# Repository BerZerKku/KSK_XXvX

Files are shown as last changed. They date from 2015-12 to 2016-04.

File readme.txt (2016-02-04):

Плата KSK

02v5

При вводе СП в 1С учесть что часть элементов отсутствует в БД.
На сборочнике надо перевернуть один стабилитрон, спросить у Феди.

Код ПП: 3.140.016
Код ПП в сборе: 2.140.243

Стэк:
35мкм  TOP 
1.5мм e=4.5
35мкм  BOTTOM

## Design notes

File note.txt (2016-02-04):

Диоды VD101,102 заменить на SMBJ48A.
Диоды VD1,VD13 заменить на TZMC5V1-GS08.
Чип-резисторы R3,R25.. заменить на 0603-21K-1%.

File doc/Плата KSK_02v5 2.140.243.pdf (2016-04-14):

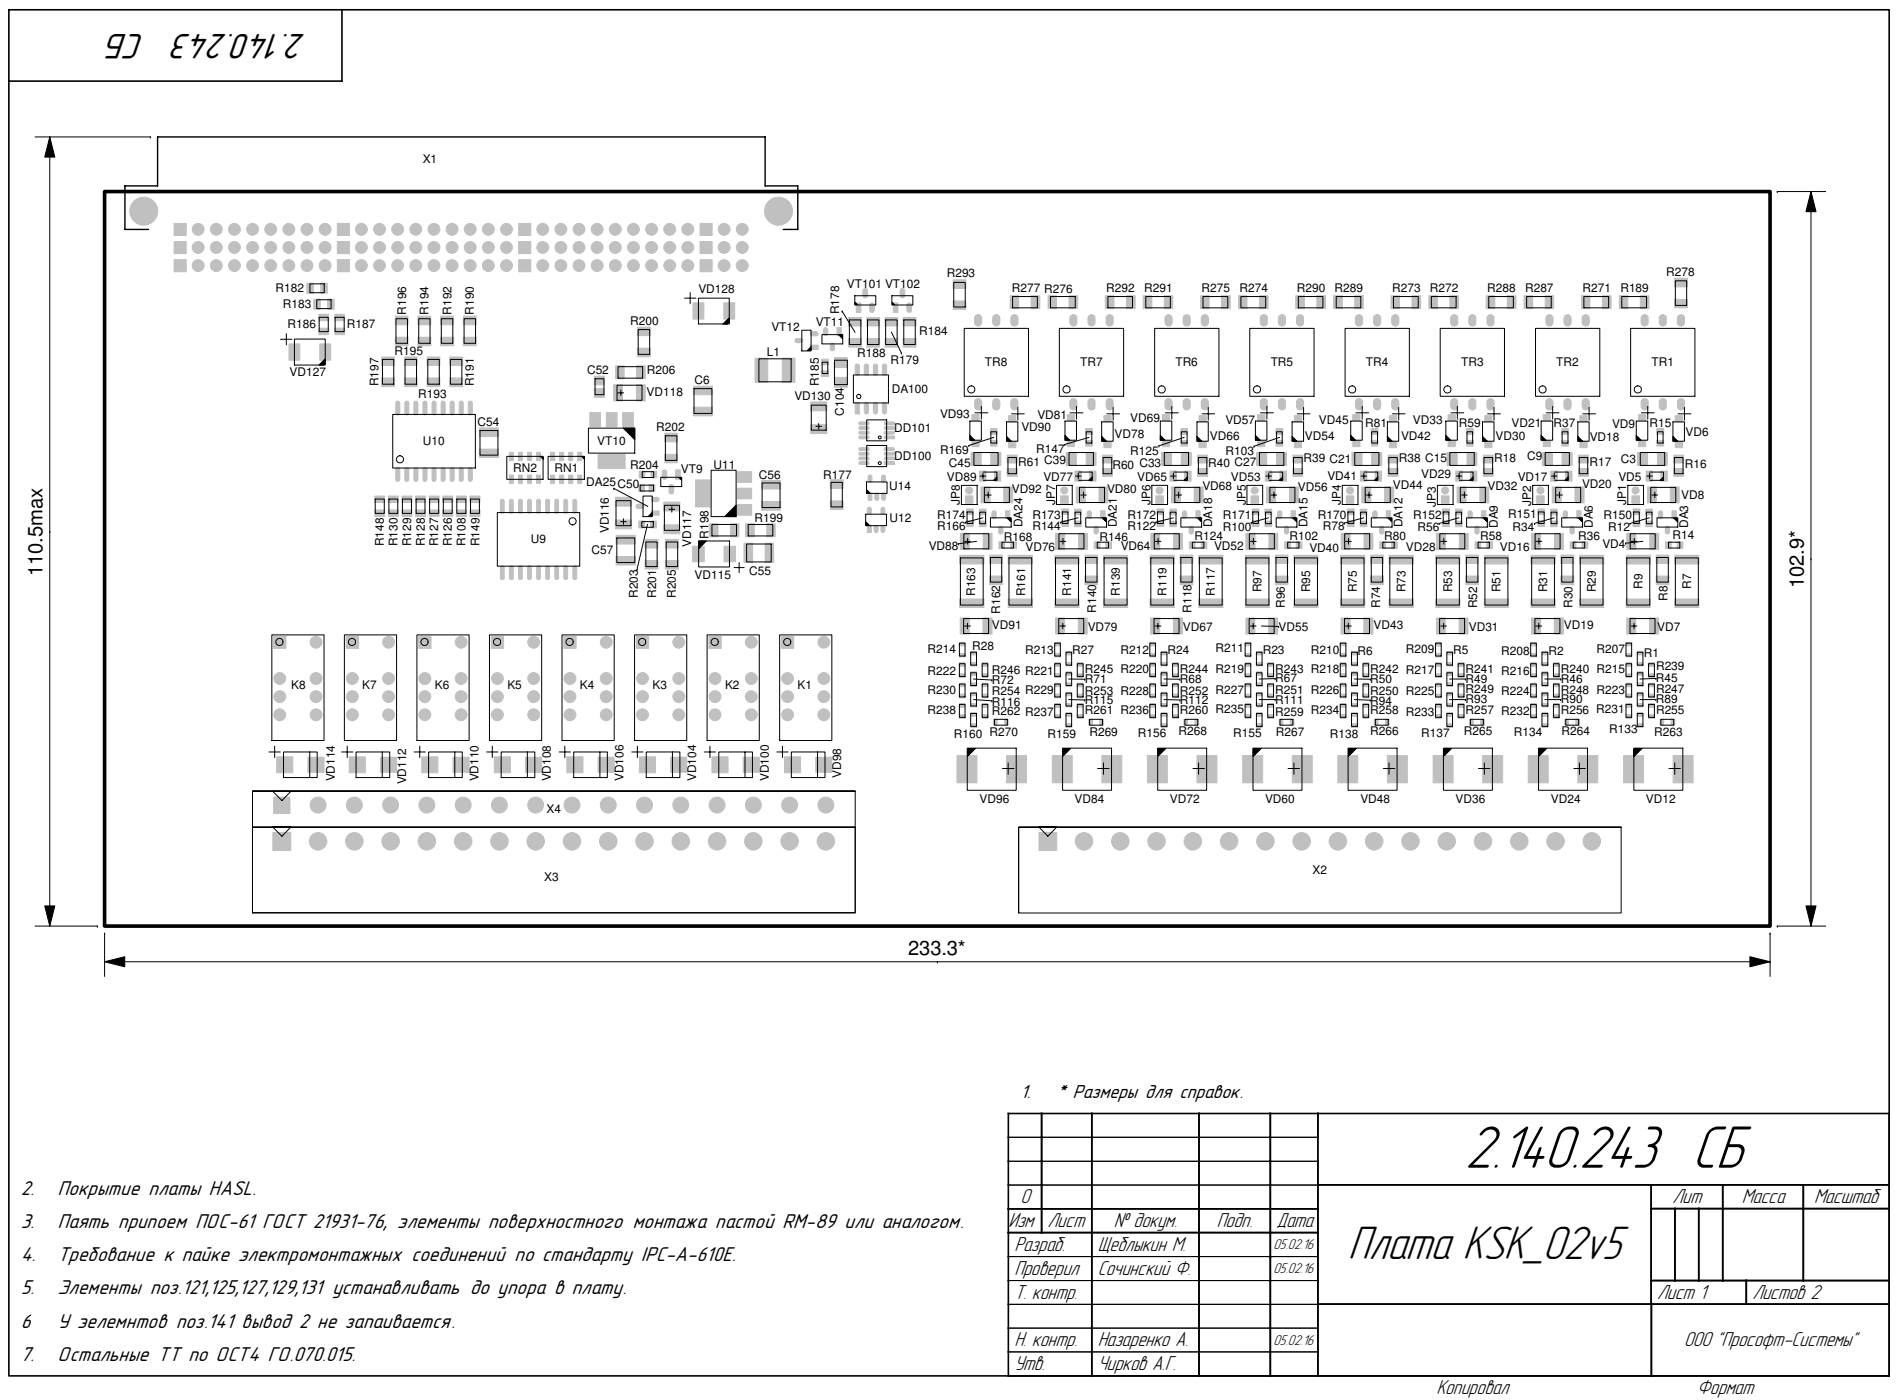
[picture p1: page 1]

2. Покрытие платы HASL.
3. Паять припоем ПОС-61 ГОСТ 21931-76, элементы поверхностного монтажа пастой RM-89 или аналогом.
4. Требование к пайке электромонтажных соединений по стандарту IPC-A-610E.
5. Элементы поз.121,125,127,129,131 устанавливать до упора в плату.
6 У эелемнтов поз.141 вывод 2 не запаивается.
7. Остальные ТТ по ОСТ4 ГО.070.015.

0 | | | | | Ïëàòà KSK_02v5 | Ëèò | Ìàññà | Ìàñøòàá
Èçì | Ëèñò | ¹ äîêóì. | Ïîäï. | Äàòà
Ðàçðàá. | | Ùåáëûêèí Ì. | | 05.02.16
Ïðîâåðèë | | Ñî÷èíñêèé Ô. | | 05.02.16
Ò. êîíòð. | | | | | Ëèñò 1 | Ëèñòîâ 2

Í. êîíòð. | Íàçàðåíêî À. | 05.02.16
Óòâ. | ×èðêîâ À.Ã.

ÎÎÎ "Ïðîñîôò-Ñèñòåìû"

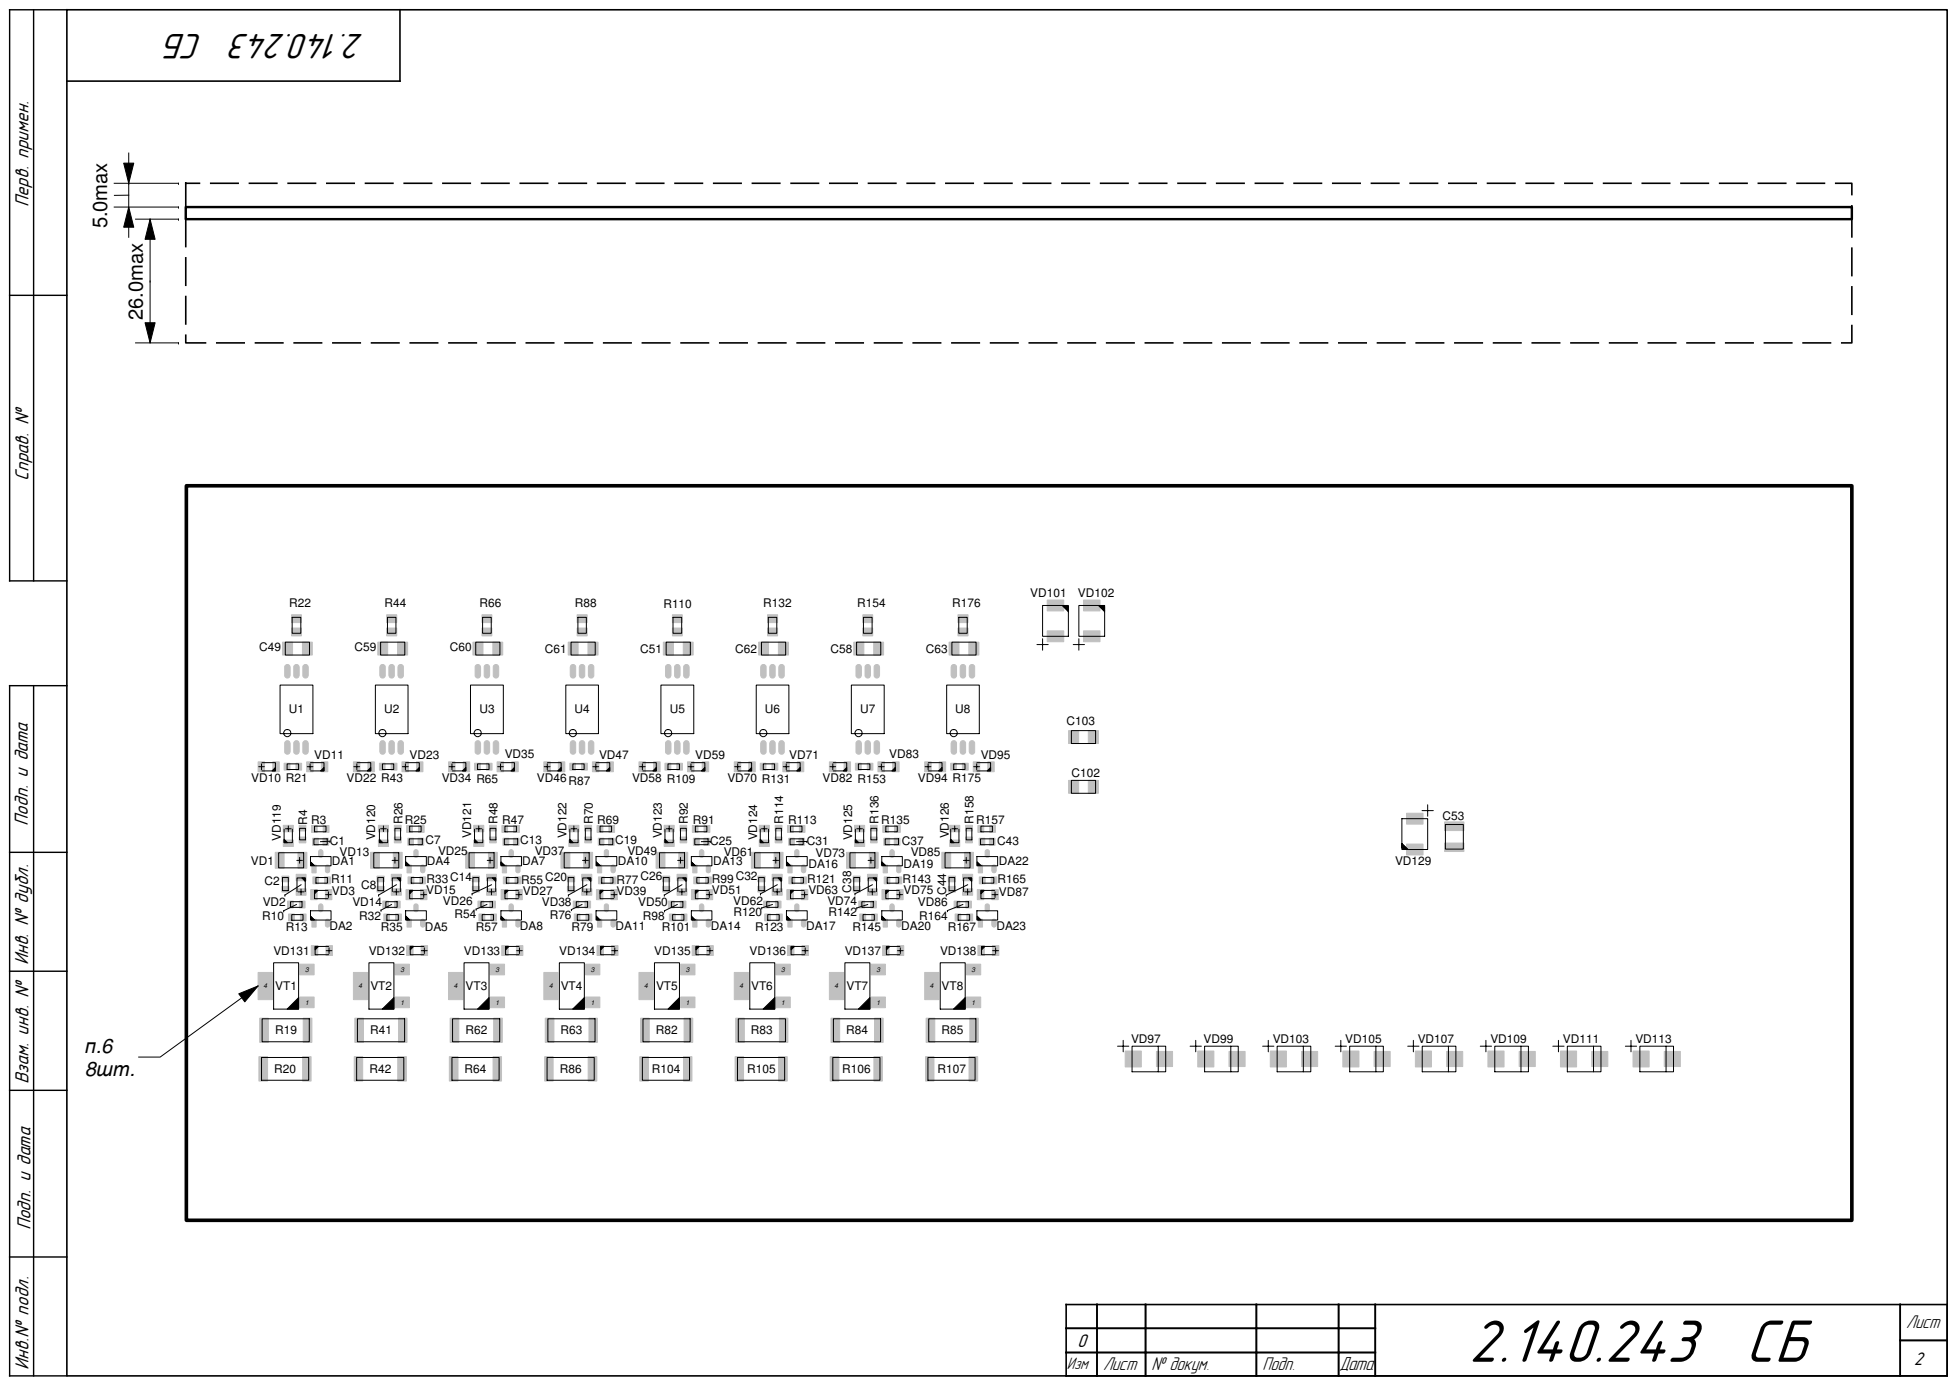
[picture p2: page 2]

Инв.№ подл. Подп. и дата Взам. инв. № Инв. № дубл. Подп. и дата Справ. № Перв. примен. R32 R120 R142 R164 R11 R33 R55 R77 R99 R121 R143 R165

№ | Наименование | Корпус | Кол. | Поз. | Примечание
| | | | | 2.140.243

1

Изм | Лист | № докум. | Подп. | Дата
Разраб. | Щеблыкин М.В | | 13.04.16 | Плата KSK_02v5 Спецификация | Лит. «Прософт-Системы» Н.контр. | Лист | Листов
Провер. | Вершинин А.С. | | 13.04.16 | | | 1 | 5

### ООО

Назаренко А.Н. | 13.04.16
Утв. | Чирков А.Г.
1 | Сборочный чертеж
| 2.140.243 rev.0 | 1

ДЕТАЛИ
3 | Плата печатная
| 3.140.016 KSK_02v5 | 1

ПРОЧИЕ ИЗДЕЛИЯ

Диоды

5 | 1.5SMC300CA SMC | DO-214AB | 8

VD12,VD24,VD36,VD48,VD60,VD72, VD84,VD96

7 | MCL4448 MicroMELF Vishay | MicroMELF | 56

VD2,VD3,VD5,VD10,VD11,VD14,VD15, VD17,VD22,VD23,VD26,VD27,VD29, VD34,VD35,VD38,VD39,VD41,VD46, VD47,VD50,VD51,VD53,VD58,VD59, VD62,VD63,VD65,VD70,VD71,VD74, VD75,VD77,VD82,VD83,VD86,VD87, VD89,VD94,VD95,VD119-VD126, VD131-VD138

9

MBR0520 Шоттки 20В 500мА SOD123

| Fairchild Semiconductor | SOD123 | 16 | VD6,VD9,VD18,VD21,VD30,VD33,
| | | | VD42,VD45,VD54,VD57,VD66,VD69,
| | | | VD78,VD81,VD90,VD93
11 | P6SMB300CA | DO-214AA | 16 | VD97-VD100,VD103-VD114
13 | SMBJ48A | DO-214AA | 2 | VD101,VD102
15 | SM6T30A DO-214AA | DO-214AA | 3 | VD127-VD129
17 | STPS160U SMB STM | DO-214AA | 1 | VD115
19 | TZMC15-GS08 Minimelf Vishay | MiniMelf | 1 | VD118
21 | TZMC5V1 MiniMELF SOD-80 Vishay | MiniMelf | 35

VD1,VD4,VD7,VD8,VD13,VD16,VD19, VD20,VD25,VD28,VD31,VD32,VD37, VD40,VD43,VD44,VD49,VD52,VD55, VD56,VD61,VD64,VD67,VD68,VD73, VD76,VD79,VD80,VD85,VD88,VD91, VD92,VD116,VD117,VD130

2.140.243

Лист

Изм | Лист | № докум. | Подп. | Дата
25 | Индуктивность LQH43CN100K 650mA
10uH 10% 1812 Murata | 1812 | 1 | L1

Конденсаторы

29 | 0603 NP0 50V 10pF 5% | 0603 | 8 | C1,C7,C13,C19,C25,C31,C37,C43
31 | 0603 X7R 50V 0.01uF 10% | 0603 | 1 | C50
33 | 0603 X7R 50V 0.033uF 10% | 0603 | 8 | C2,C8,C14,C20,C26,C32,C38,C44
35 | 0805 X7R 50V 0.1uF 10% | 0805 | 1 | C52
37 | 1206 NP0 50V 200pF 5% | 1206 | 8 | C3,C9,C15,C21,C27,C33,C39,C45
39 | 1206 X7R 50V 1uF 10% | 1206 | 11 | C49,C51,C58-C63,C102-C104
41 | 1210 X7R 50V 4.7uF 10% | 1210 | 6 | C6,C53-C57

Микросхемы

45 | ACPL-W343-000E SO6 Avago | SO6 | 8 | U1-U8
47 | ISO1541D SOIC8 TI | SOIC8 | 1 | DA100
49 | LM317AEMP SOT223 TI | SOT223 | 1 | U11
51 | SN74LVC1G14DBV SOT23-5 TI | SOT23-5 | 2 | U12,U14
53 | SN74LVC2G74DCT SSOP8 TI | SSOP8 | 2 | DD100,DD101
55 | STM1061N38WX6F SOT23 STM | SOT23-3 | 25 | DA1-DA25
57 | ULN2803ADW SOIC18 TI | SOIC18 | 2 | U9,U10

Резисторы

61 | 0603 100 5% | 0603 | 8 | R10,R32,R54,R76,R98,R120,R142, R164
63 | 0603 1K 5% | 0603 | 1 | R185
65 | 0603 10K 1% | 0603 | 1 | R204
67 | 0603 21K 1% | 0603 | 8

R3,R25,R47,R69,R91,R113,R135, R157

69 | 0603 22K 5% | 0603 | 16 | R15,R21,R37,R43,R59,R65,R81,R87, R103,R109,R125,R131,R147,R153, R169,R175
71 | 0603 42.2K 1% | 0603 | 16 | R12,R34,R56,R78,R100,R122,R144, R150-R152,R166,R170-R174
73 | 0603 100K 5% (KTR03EZPJ104 ) | 0603 | 96 | R1,R2,R5,R6,R23,R24,R27,R28,R45, R46,R49,R50,R67,R68,R71,R72,R89, R90,R93,R94,R111,R112,R115,R116, R133,R134,R137,R138,R155,R156, R159,R160,R207-R270
75 | 0603 100K 1% | 0603 | 8 | R11,R33,R55,R77,R99,R121,R143, R165
77 | 0603 390K 5% | 0603 | 8 | R14,R36,R58,R80,R102,R124,R146, R168
79 | 0603 750K 1% | 0603 | 8 | R4,R26,R48,R70,R92,R114,R136, R158
81 | 0603 1M 5% | 0603 | 9 | R13,R35,R57,R79,R101,R123,R145, R167,R203
83 | 0805 0 | 0805 | 4 | R182,R183,R186,R187
85 | 0805 100 5% | 0805 | 8 | R22,R44,R66,R88,R110,R132,R154, R176
87 | 0805 510 5% | 0805 | 8 | R16-R18,R38-R40,R60,R61
89 | 0805 18K 5% | 0805 | 8 | R108,R126-R130,R148,R149
91 | 1206 1 1% | 1206 | 2 | R178,R179
93 | 1206 62 5% | 1206 | 3 | R184,R188,R202
95 | 1206 270 5% | 1206 | 1 | R198
97 | 1206 1K 5% | 1206 | 1 | R199
99 | 1206 2K 5% | 1206 | 9 | R190-R197,R200
101 | 1206 3.3K 5% | 1206 | 1 | R177
103 | 1206 4.7K 5% | 1206 | 16 | R189,R271-R278,R287-R293
105 | 1206 10K 5% | 1206 | 2 | R201,R205
107 | 1206 20K 5% | 1206 | 1 | R206
109 | 1206 750K 1% | 1206 | 8

R8,R30,R52,R74,R96,R118,R140, R162

111 | 2512 30K 5% | 2512 | 16 | R7,R9,R29,R31,R51,R53,R73,R75, R95,R97,R117,R119,R139,R141, R161,R163
113 | 2512 470 5% | 2512 | 16 | R19,R20,R41,R42,R62-R64, R82-R86,R104-R107
117 | Чип-резисторная сборка 1206x4
4.7K 5% | SMT-8 | 2 | RN1,RN2
121 | Реле G6S224DC 24VDC 2 Form C
0.5A/125VAC Omron | DIP-8 | 8 | K1-K8

Разъемы

125 232-376 Угловая Вилка 5,08 мм 16-поз

| 16 | 1 | X4
127 | 231-576/001-000 Вилка 1,2X1,2
шаг 5,08 мм | 16 | 2 | X2,X3
129 | DIN41612 09031966921 HARTING | DIN96 | 1 | X1 | 3x32 96 MR
131 | PLL1.27-2 | 2 | 8 | JP1-JP8

Транзисторы

135 | BC817-40 SOT23 | SOT23-3 | 2 | VT11,VT12
137 | BCP53-16 SOT223 | SOT223 | 1 | VT10
139 | IRLML2060 60V 1.2A SOT23-3 IR | SOT23-3 | 3 | VT9,VT101,VT102
141 | STN1NK60Z 600V 0.3A SOT223 STM
| (STN1NK80Z STM, STN3N45K3 STM) | SOT223 | 8 | VT1-VT8
145 | Трансформатор 78253/55MVC
Murata | SOIC6 | 8 | TR1-TR8

Лист регистрции изменений СП
№ Изм. | № замененных (измененных) страниц | Дата ревизии | Краткое содержание и причина внесения изменений | Примечание
0 | вновь | 05.02.16
1 | 2 | 13.04.16 | В поз.55 исправлено поз.обозначение U36 на DA25.

Исполнения:

Лист регистрции изменений СБ
№ Изм. | № замененных (измененных) страниц | Дата ревизии | Краткое содержание и причина внесения изменений | Примечание
0 | вновь | 05.02.16

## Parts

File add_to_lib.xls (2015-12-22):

производитель | наименование | корпус | назначение
 | ULN2803A | SOIC (18) | Сборка транзисторв
Omron | G3VM-351E |  | Оптореле
Omron | G6S-2; 24VDC |  | Реле
axicom | fx2 D 3212 |  | Реле
AVAGO | ACPL-K376-000E |  | Оптрон
MURATA | 78253/55MVC |  | Трансформатор
LITTLEFUSE, VISHAY | 1.5SMC300CA 300В |  | Супрессор
murata | DE1B3KX471K |  | Конденсатор 470p
RECTRON (DIOTEC) | SM4007 |  | Диод
 | SH400M3R30B5S-1012 |  | конденсатор электролит. 3,3мкФ 400В
ON Semiconductor | MCR08MT1 |  | Тиристор
 | 30кОм ±5% | 2512 | Резистор - чип 2512
 | 200кОм ±5% | 0805 | Резистор - чип 0805
 | 820 Ом ±5% | 2010 | Резистор - чип 2010
Стабилитрон BZX84C13 13В FAIRCHILD (BZX84C13LT1G ON, BZX84-C13 NXP)
Резистор - чип 0805 8.2кОм ±5%
Термистор JJCR472J400HB52PU505(JOYIN), 4.7 кОм, NTC
Резистор - чип 1210 15кОм ±5%
Стабилитрон BZX85B56-TR (-TAP) 56B VISHAY
Конденсатор - чип 0805 X7R 50В 0.047мкФ ±5%
Резистор - чип 1210 20кОм ±5%
Стабилитрон BZX85B56-TR (-TAP) 56B VISHAY
Транзистор IRLML2060TRPBF N-канальный MOSFET IR
Резистор - чип 0805 20кОм ±5%
Чип-резистор 2512 560 5%
Резистор - чип 0805 240 Ом ±5%
Резистор - чип 0805 750 Ом ±5%
Микросхема LM317AEMP TI
Разъем 231-576/001-000 WAGO
Резистор - чип 1206 18кОм ±5%
Разъем 232-376 двухуровненый WAGO
Резистор - чип 1206 270Ом ±5% |  |  | z
Диод STPS160U ST
Резистор - чип 1206 10кОм ±5%
Резистор - чип 1206 20кОм ±5%

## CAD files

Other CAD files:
pcb/diom7959x262n.psm
pcb/diomelf1911n.psm
pcb/diomelf3521x140n.psm
pcb/symbols/diom5436x230n.psm
pcb/symbols/diomelf1911n.psm
pcb/symbols/diomelf3521x140n.psm
pcb/symbols/pll_1_27.psm
pcb/symbols/resc1608x45n.psm
pcb/symbols/resc2013x50n.psm
pcb/symbols/sot95p230x110-3n.psm
pcb/symbols/sot95p237x112-3n.psm
pcb/symbols/sot95p280x112-5n.psm
pcb/symbols/sot95p375x128-2n.psm

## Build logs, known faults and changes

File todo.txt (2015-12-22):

KSK_02v5

1. За основу взять плату KSK_024. 
	Сохранить распиновку разъемов X1, X2, X3.
2. Схемотехнику дискретных выходов сделать аналогичной плате KPRM_02v2. 
3. Схемотехнику дискретных входов сделать аналогичной плате KPRD_04v2.
	Подумать, если возможность сделать переключатель еще и на 24В, для удобства работы в лаборатории.

Этапы работы:
1. Проверить наличие необходимых элементов в ЦБ. Заказать недостающие.
	Заявка на компоненты 24.11.2015.doc
	JJCR472J400HB52PU505 - надо найти документацию и сделать отдельную заявку!
2. Нарисовать схему. 
3. Развести плату.
	За основу взять шаблон avant_bot_klemm.brd.
	Плата двухслойная 1.5мм, металл 35мкм, маска и шелкография с обоих сторон.
4. Заказать плату.
5. Завести спецификацию в 1С.
6. Заказать комплектацию.
7. Спаять и проверить.

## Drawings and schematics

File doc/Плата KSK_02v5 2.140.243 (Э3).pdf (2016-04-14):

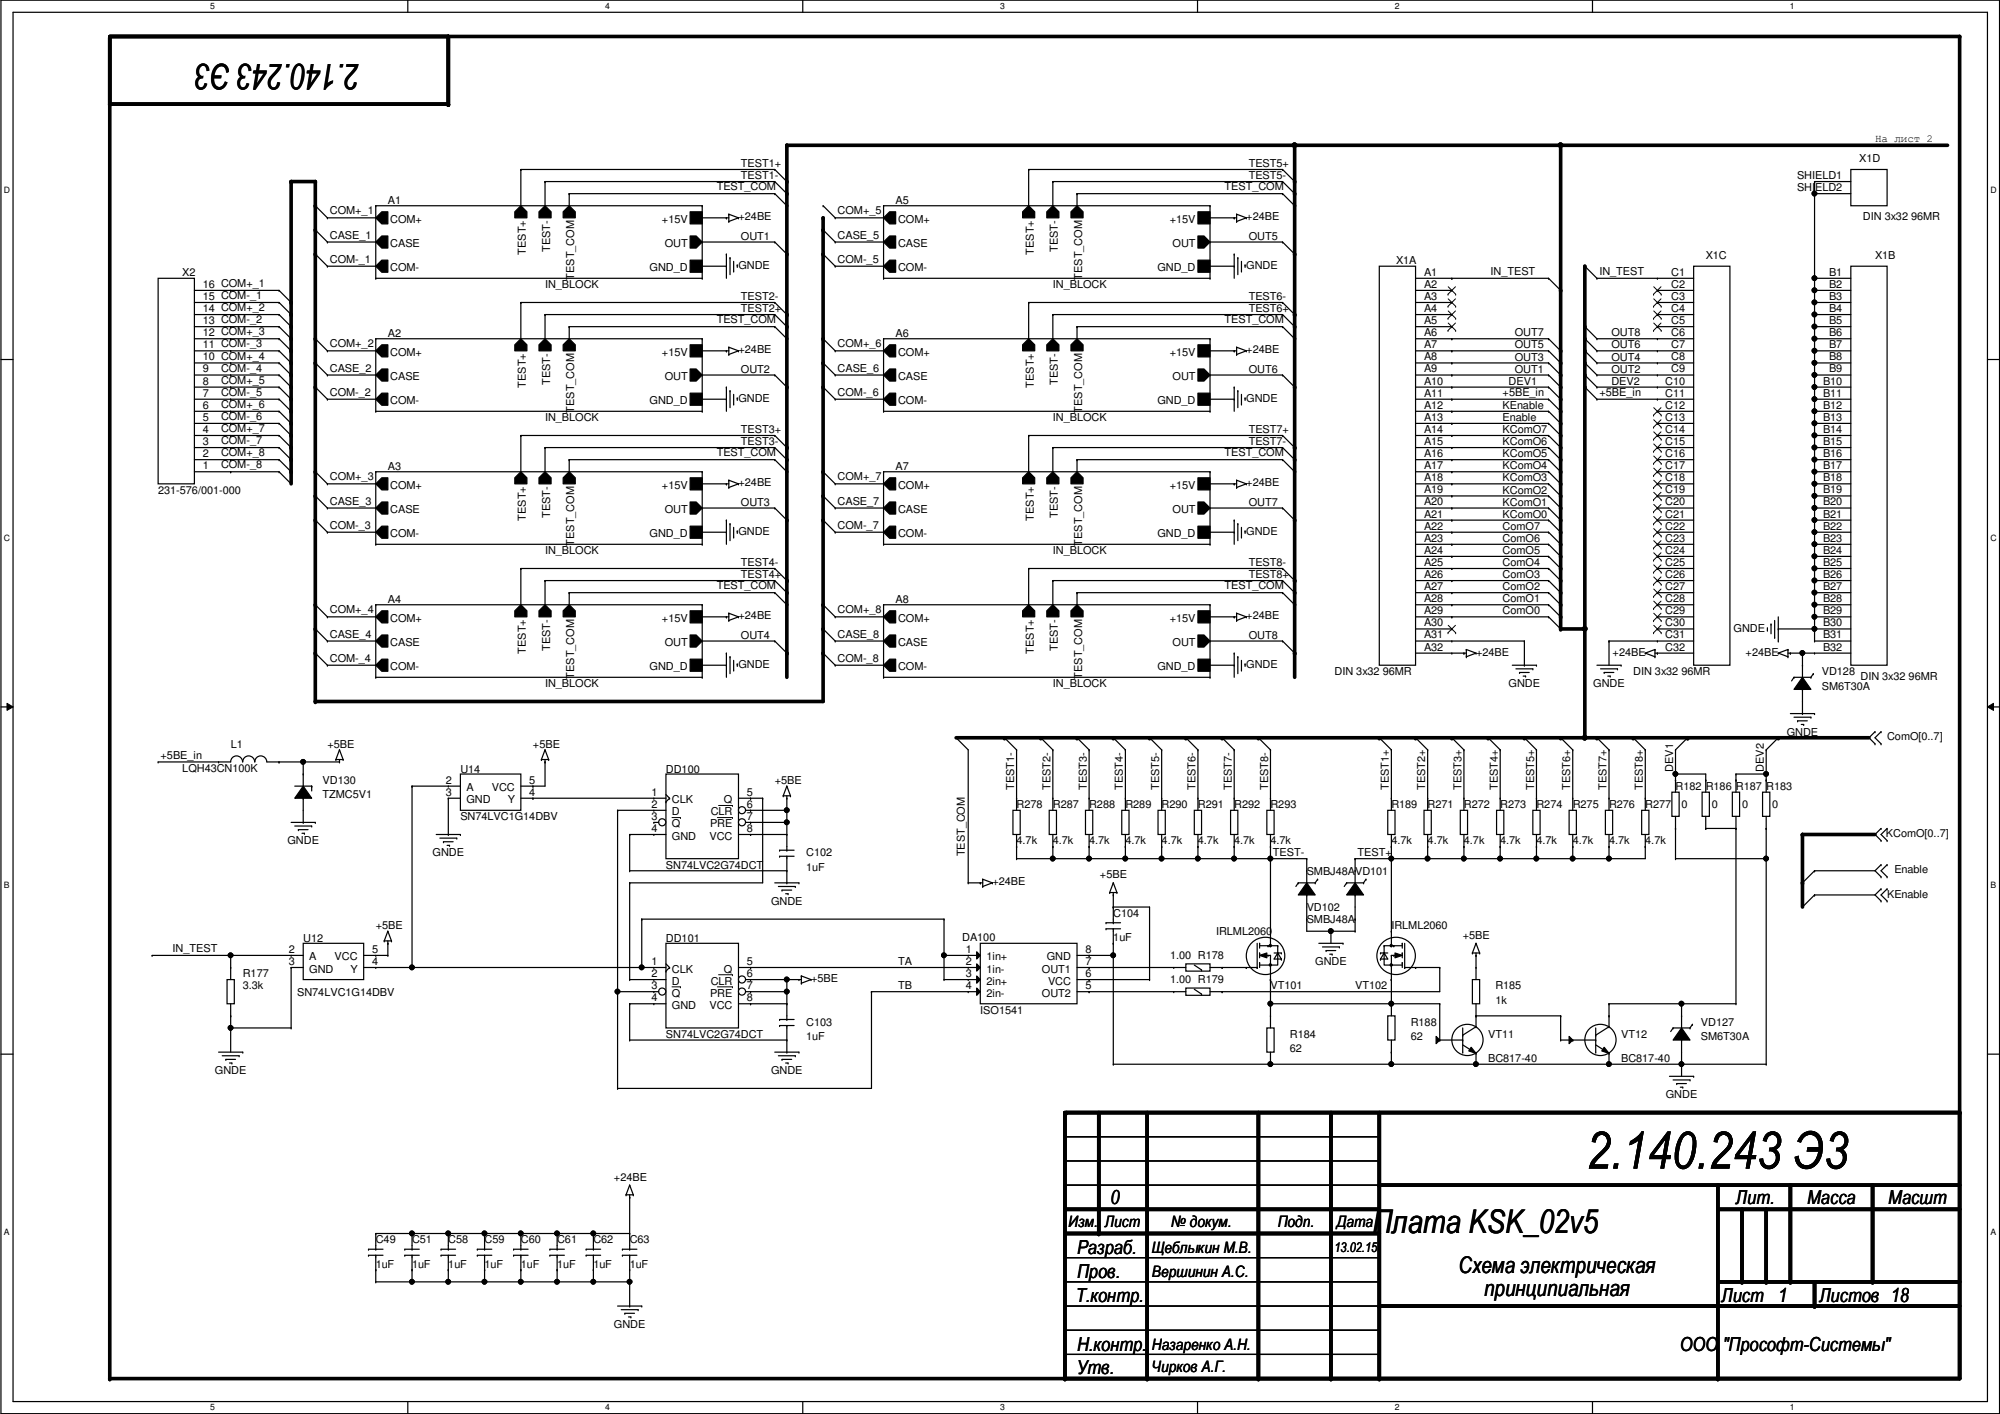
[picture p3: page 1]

0 | | | Плата KSK_02v5 Плата KSK_02v5 Плата KSK_02v5 | Схема электрическая Схема электрическая Схема электрическая | Лит. | Масса Масса Масса | Масшт Масшт Масшт
Изм. Изм. Изм. | Лист Лист Лист | № докум. № докум. № докум. | Подп. Подп. Подп. | Дата Дата Дата
Разраб. Разраб. Разраб. | | Щеблыкин М.В. Щеблыкин М.В. Щеблыкин М.В. | | 13.02.15 13.02.15 13.02.15
Пров. Пров. Пров. | | Вершинин А.С. Вершинин А.С. Вершинин А.С.
принципиальная Т.контр. принципиальная Т.контр. принципиальная Т.контр. | Лист Лист Лист 1 18 1 18 1 18 | Листов Листов Листов

Н.контр. Н.контр. Н.контр. | Назаренко А.Н. Назаренко А.Н. Назаренко А.Н.
Утв. Утв. Утв. | Чирков А.Г. Чирков А.Г. Чирков А.Г.

ООО "Прософт-Системы" ООО "Прософт-Системы" ООО "Прософт-Системы"

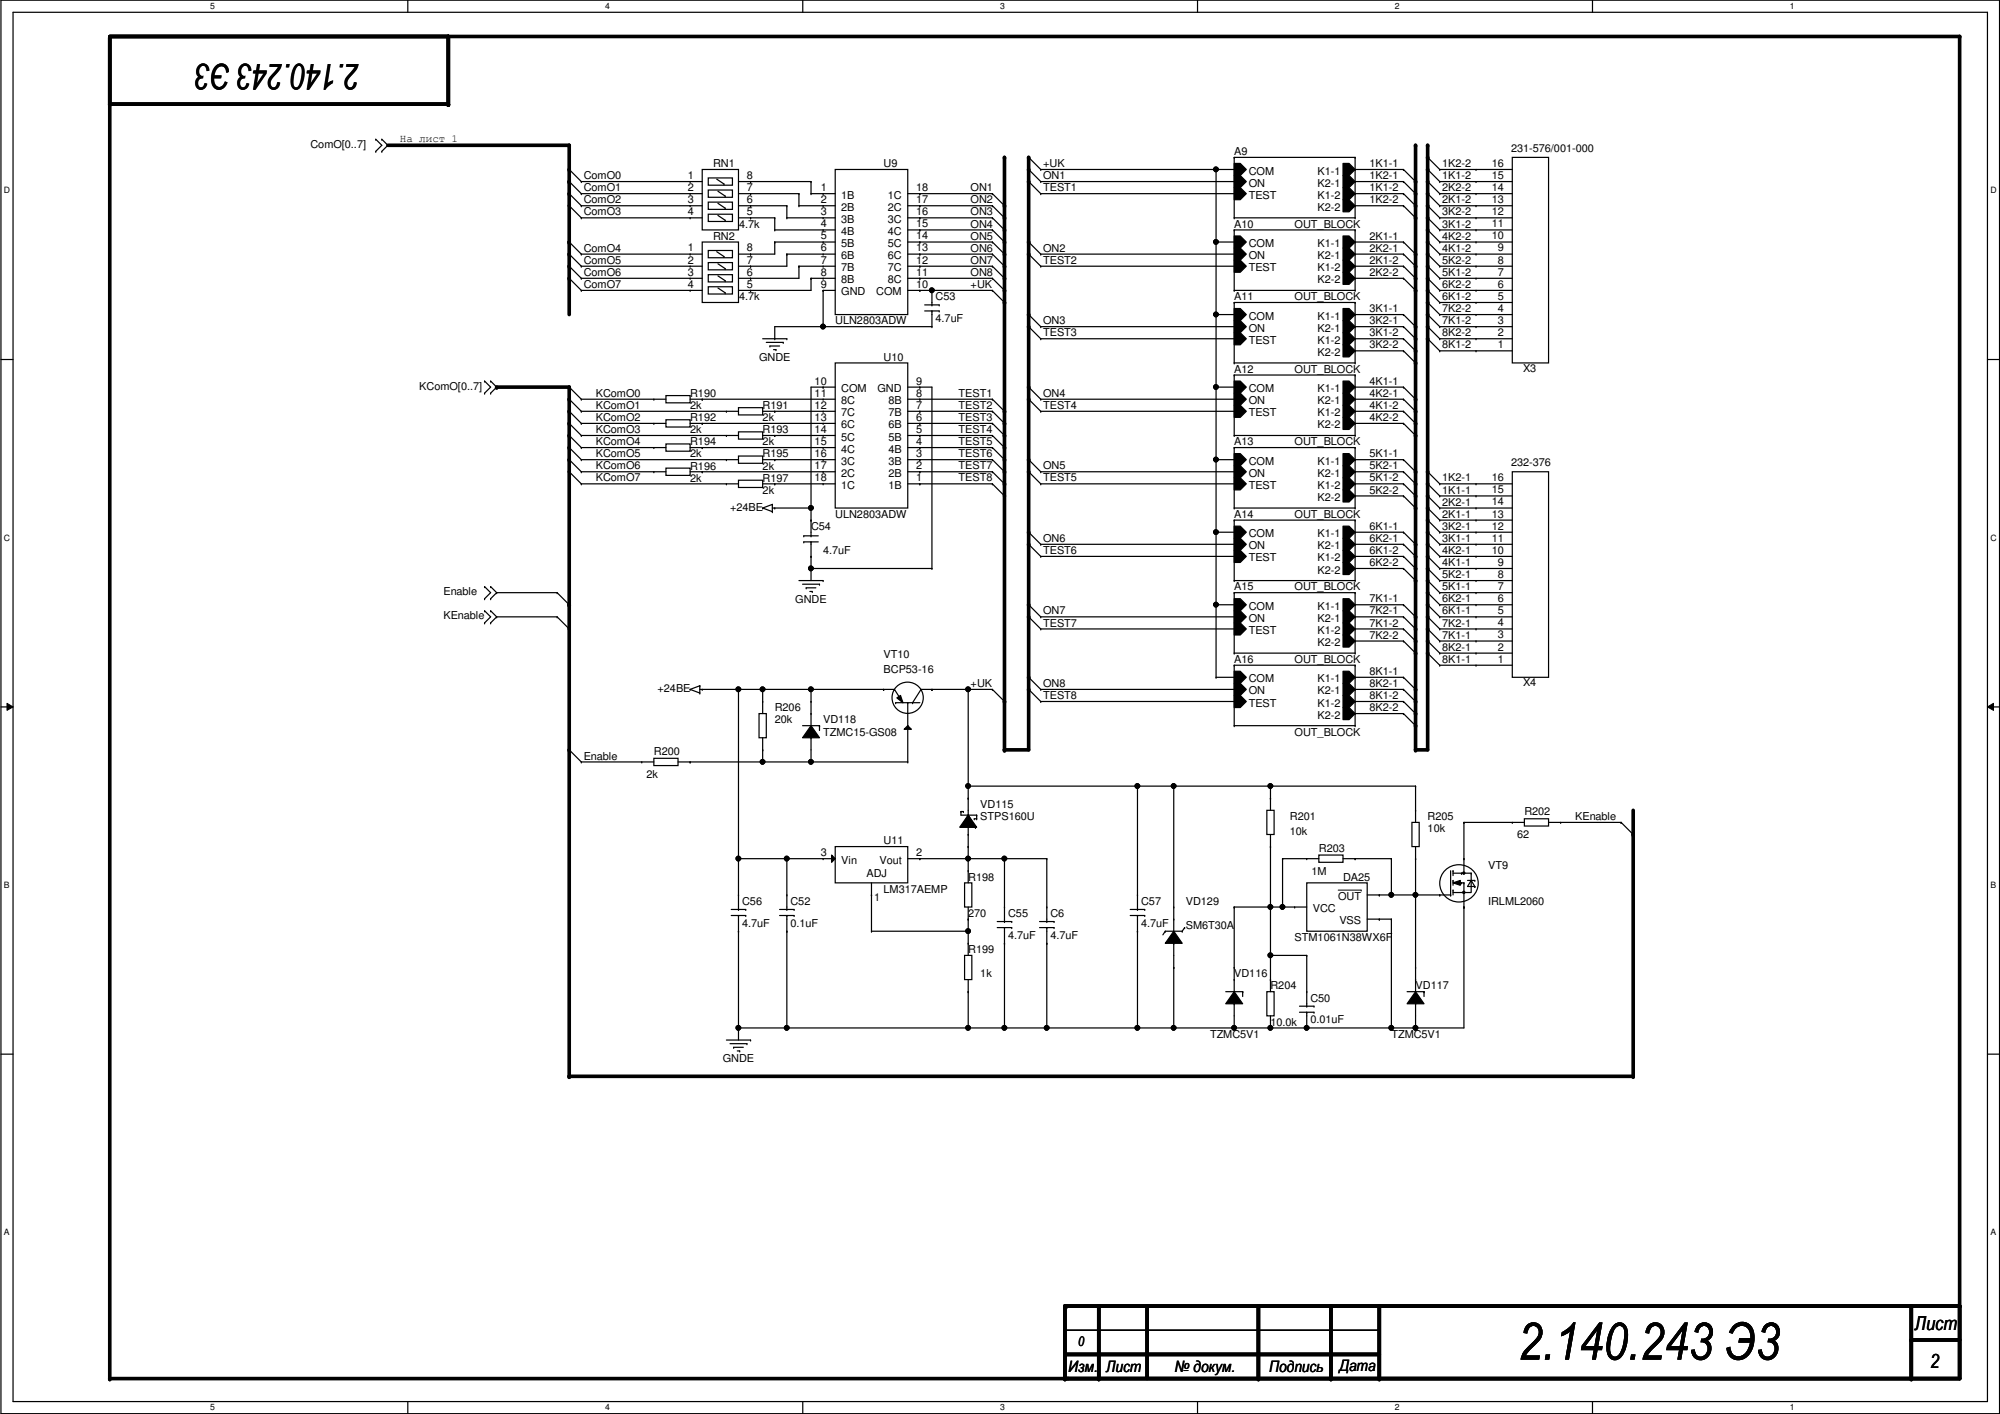
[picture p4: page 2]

Лист 2.140.243 Э3 Лист 2.140.243 Э3 Лист 2.140.243 Э3 2 ⁰ Изм. 2 ⁰ Изм. 2 ⁰

Лист | № докум. | Подпись | Дата

Изм. | Лист | № докум. | Подпись | Дата

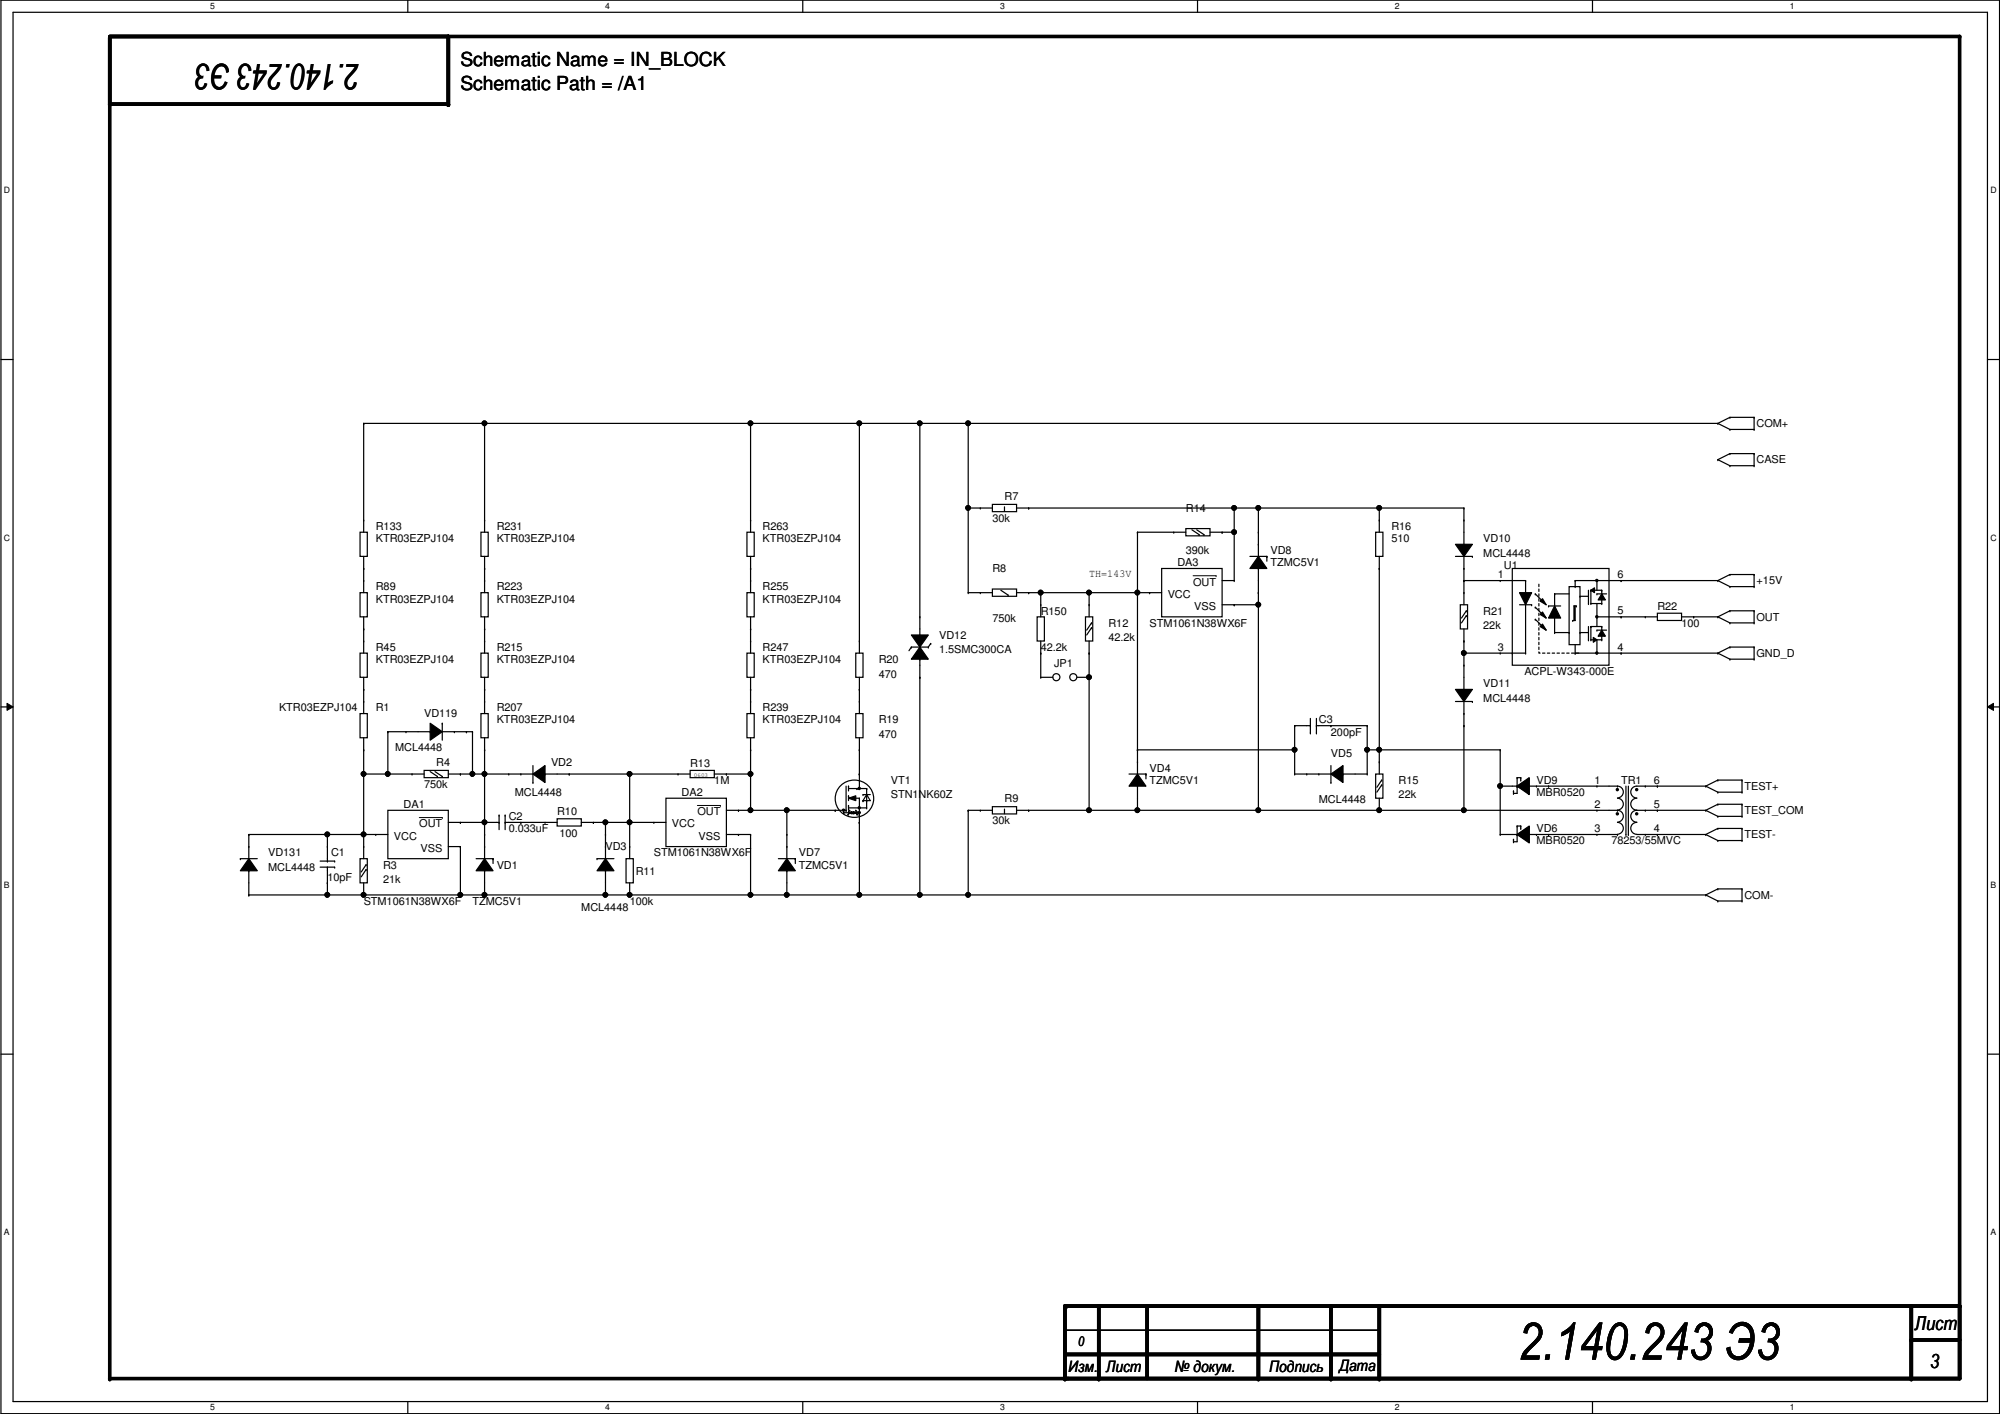
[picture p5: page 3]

Лист 2.140.243 Э3 Лист 2.140.243 Э3 Лист 2.140.243 Э3 3 ⁰ Изм. 3 ⁰ Изм. 3 ⁰

Лист | № докум. | Подпись | Дата

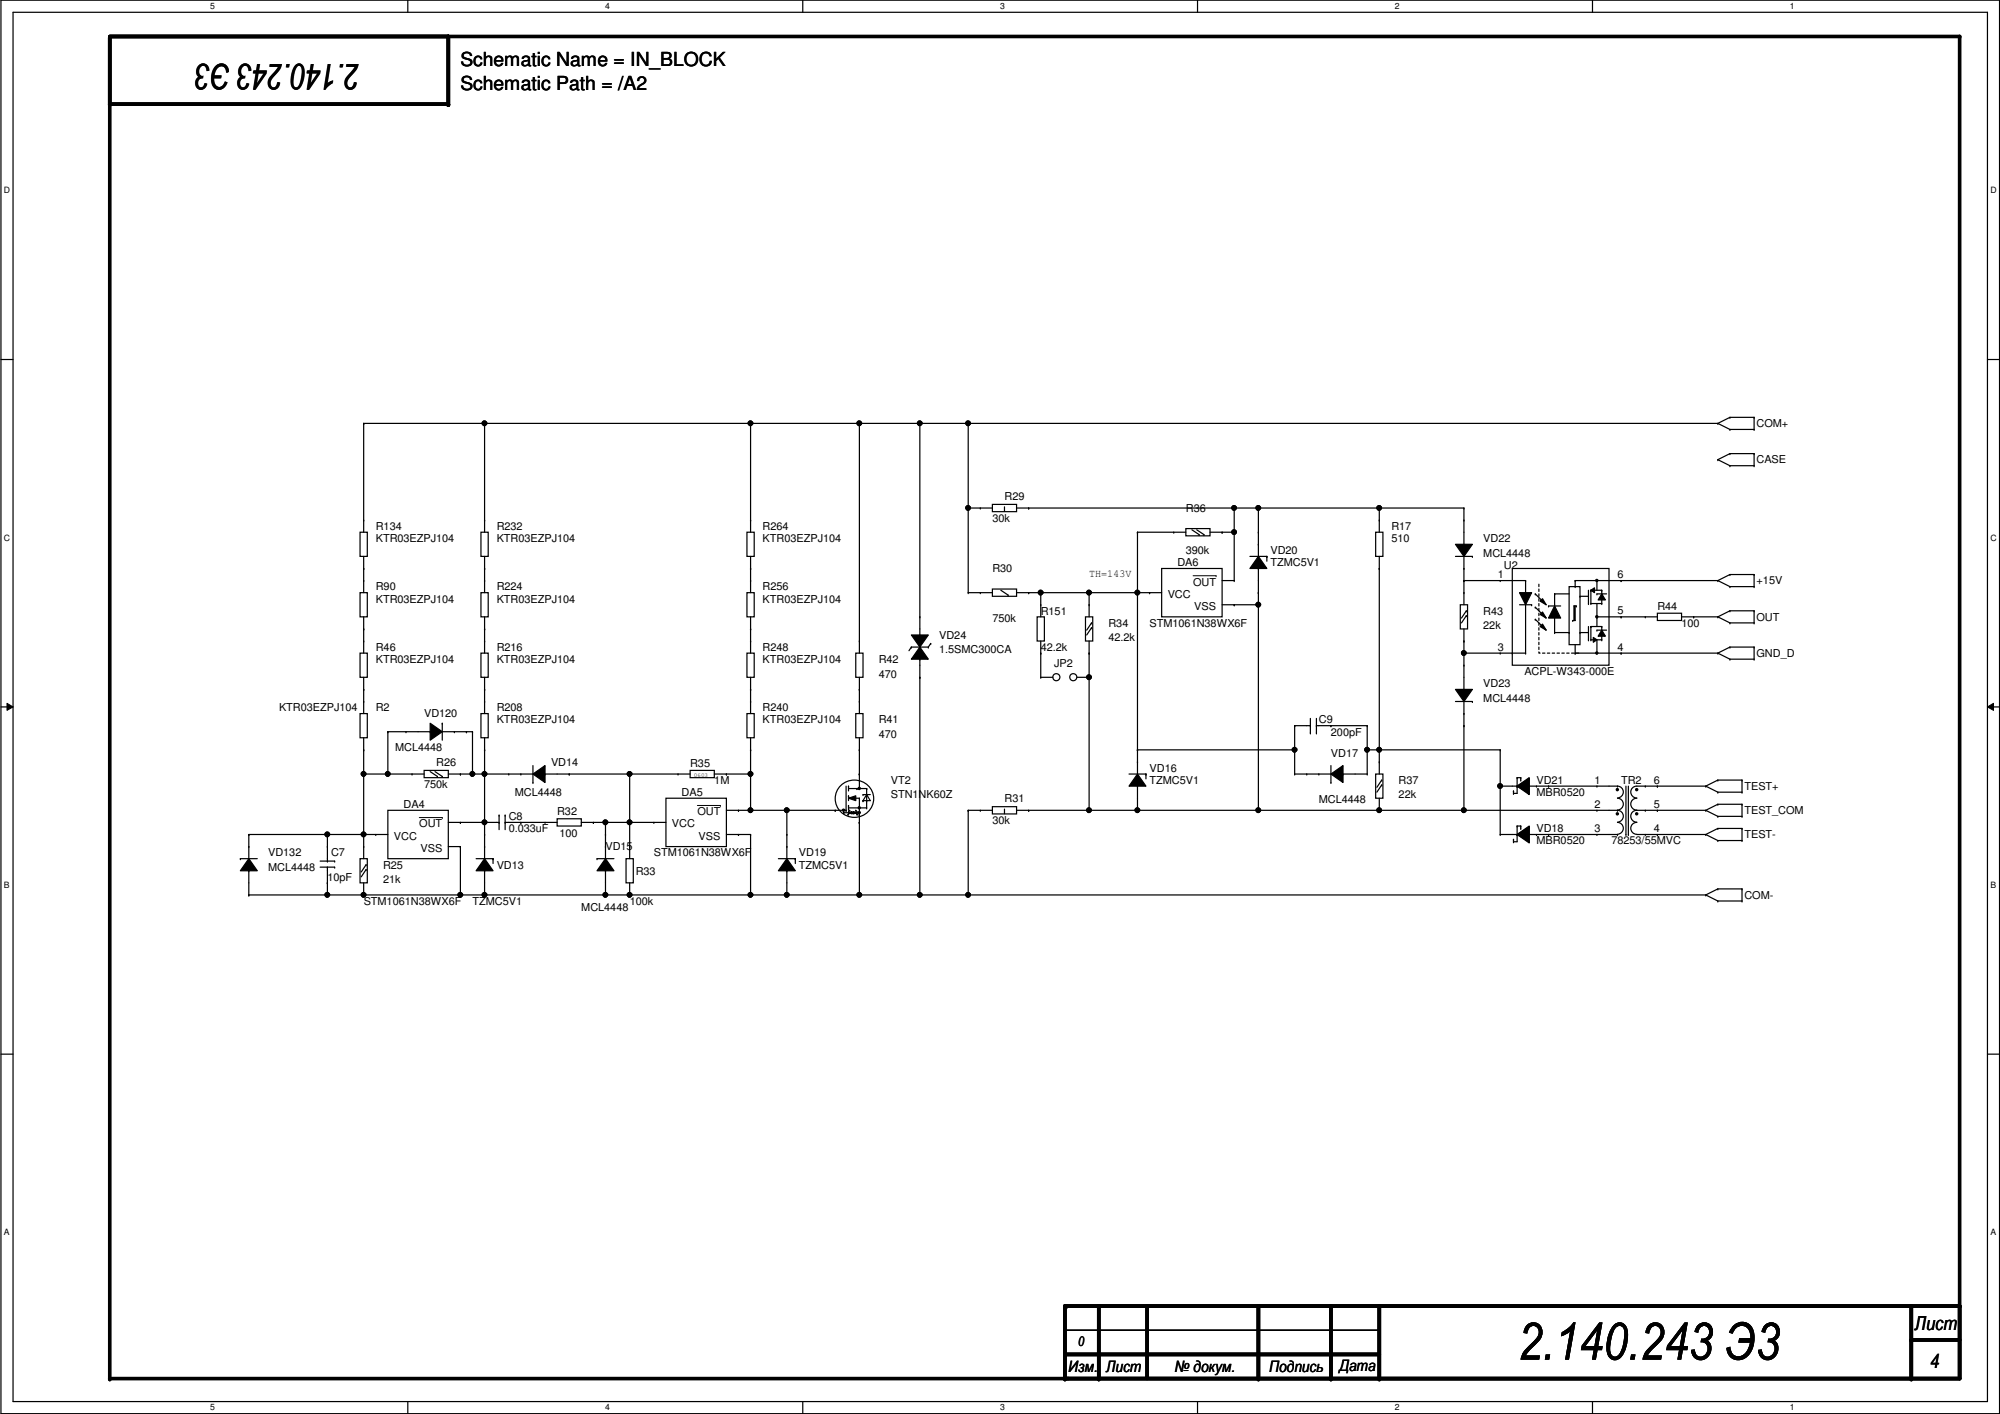
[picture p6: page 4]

Лист 2.140.243 Э3 Лист 2.140.243 Э3 Лист 2.140.243 Э3 4 ⁰ Изм. 4 ⁰ Изм. 4 ⁰

Лист | № докум. | Подпись | Дата

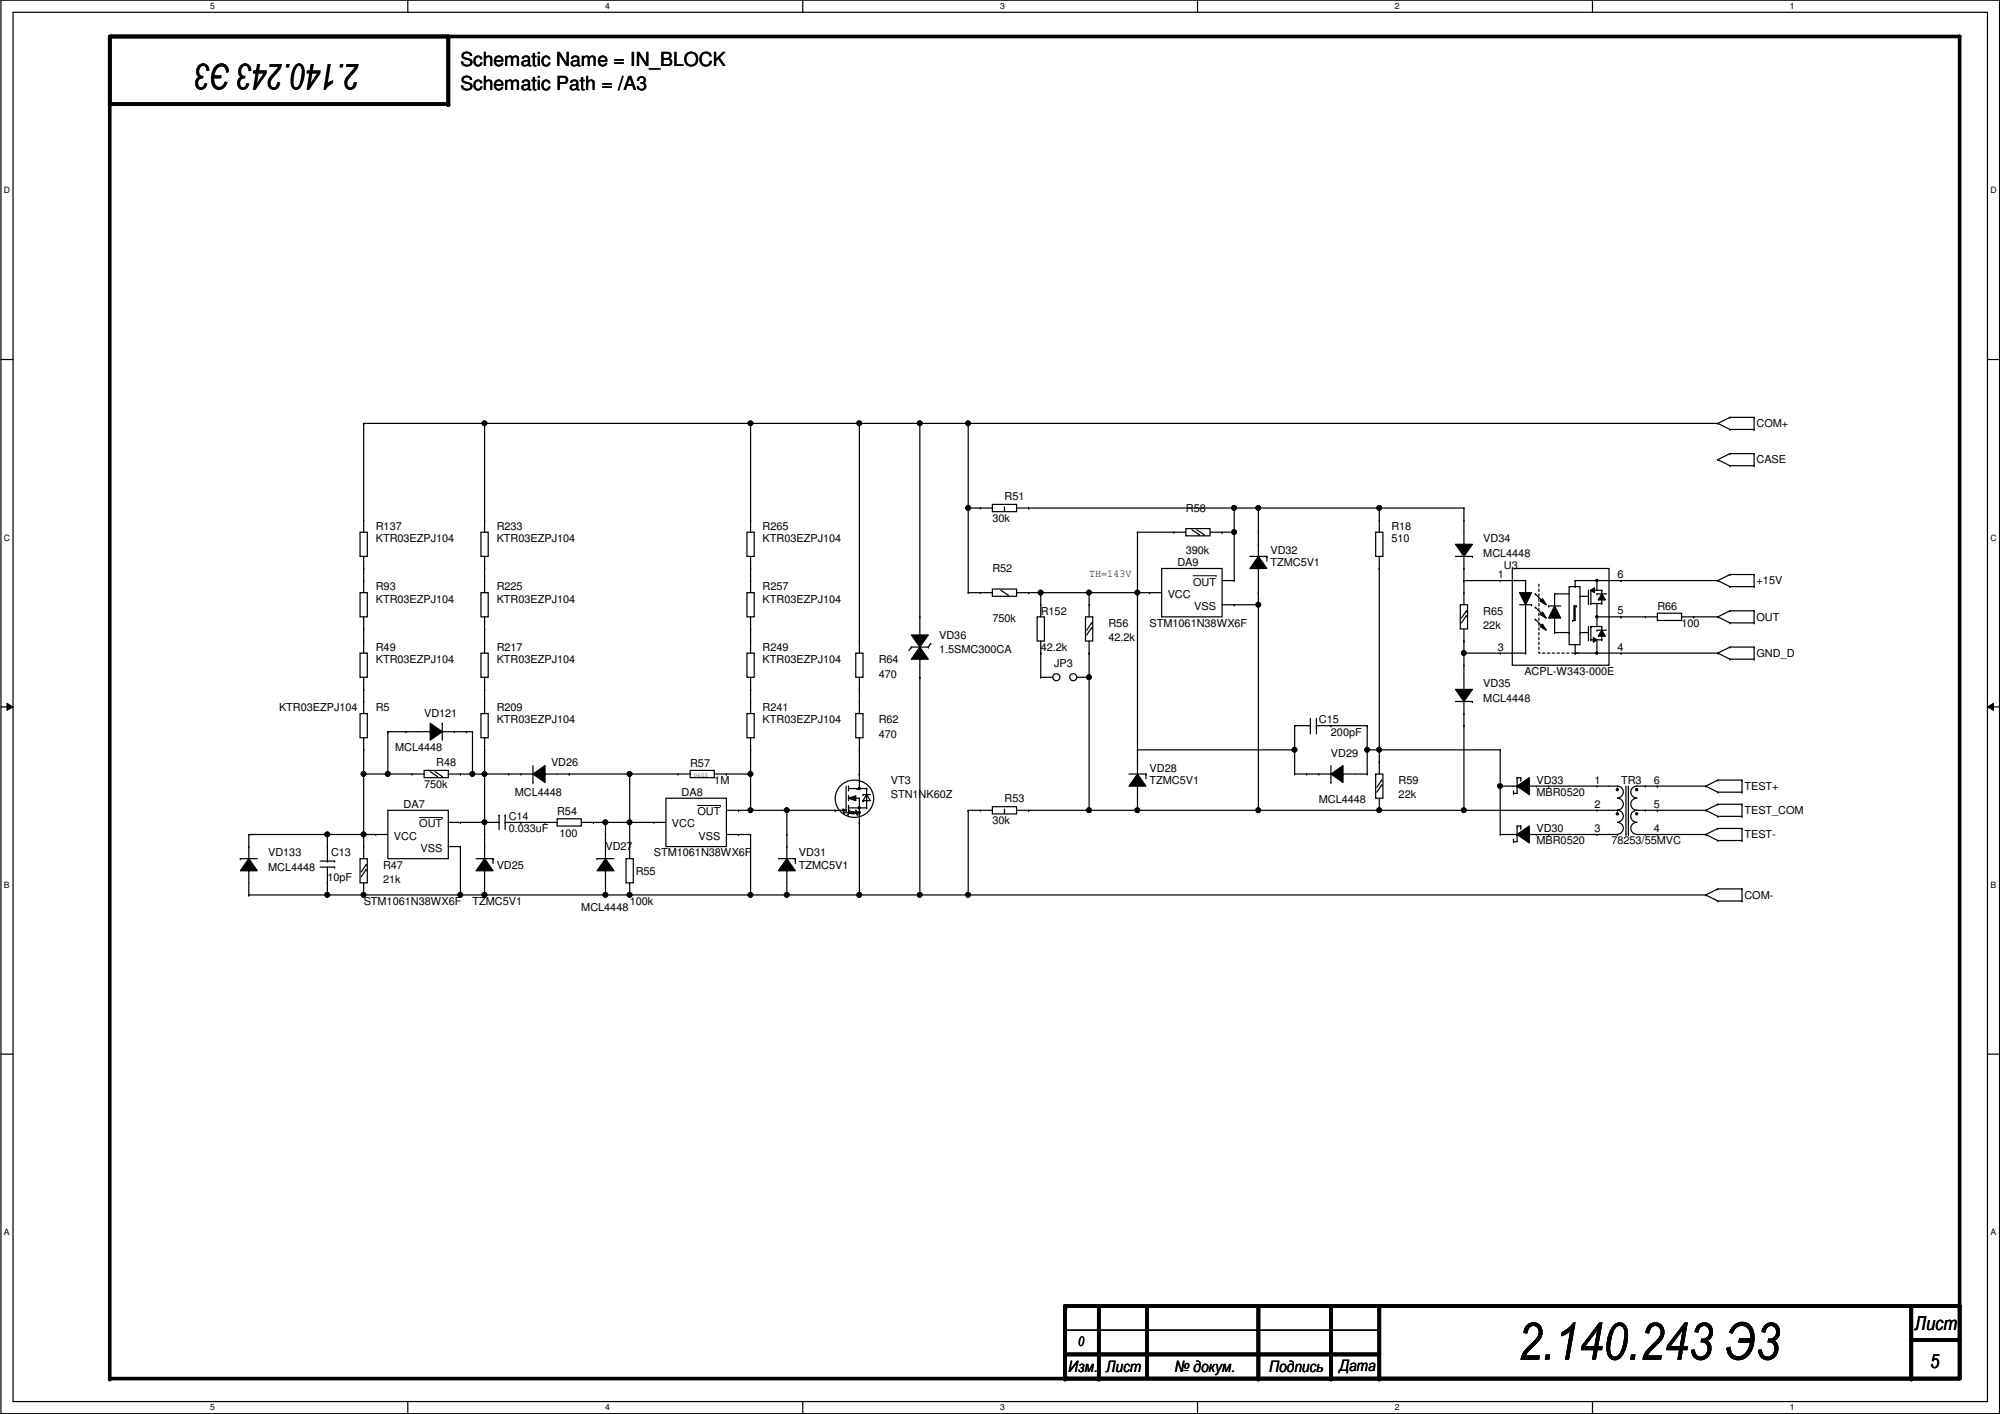
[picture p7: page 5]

Лист 2.140.243 Э3 Лист 2.140.243 Э3 Лист 2.140.243 Э3 5 ⁰ Изм. 5 ⁰ Изм. 5 ⁰

Лист | № докум. | Подпись | Дата

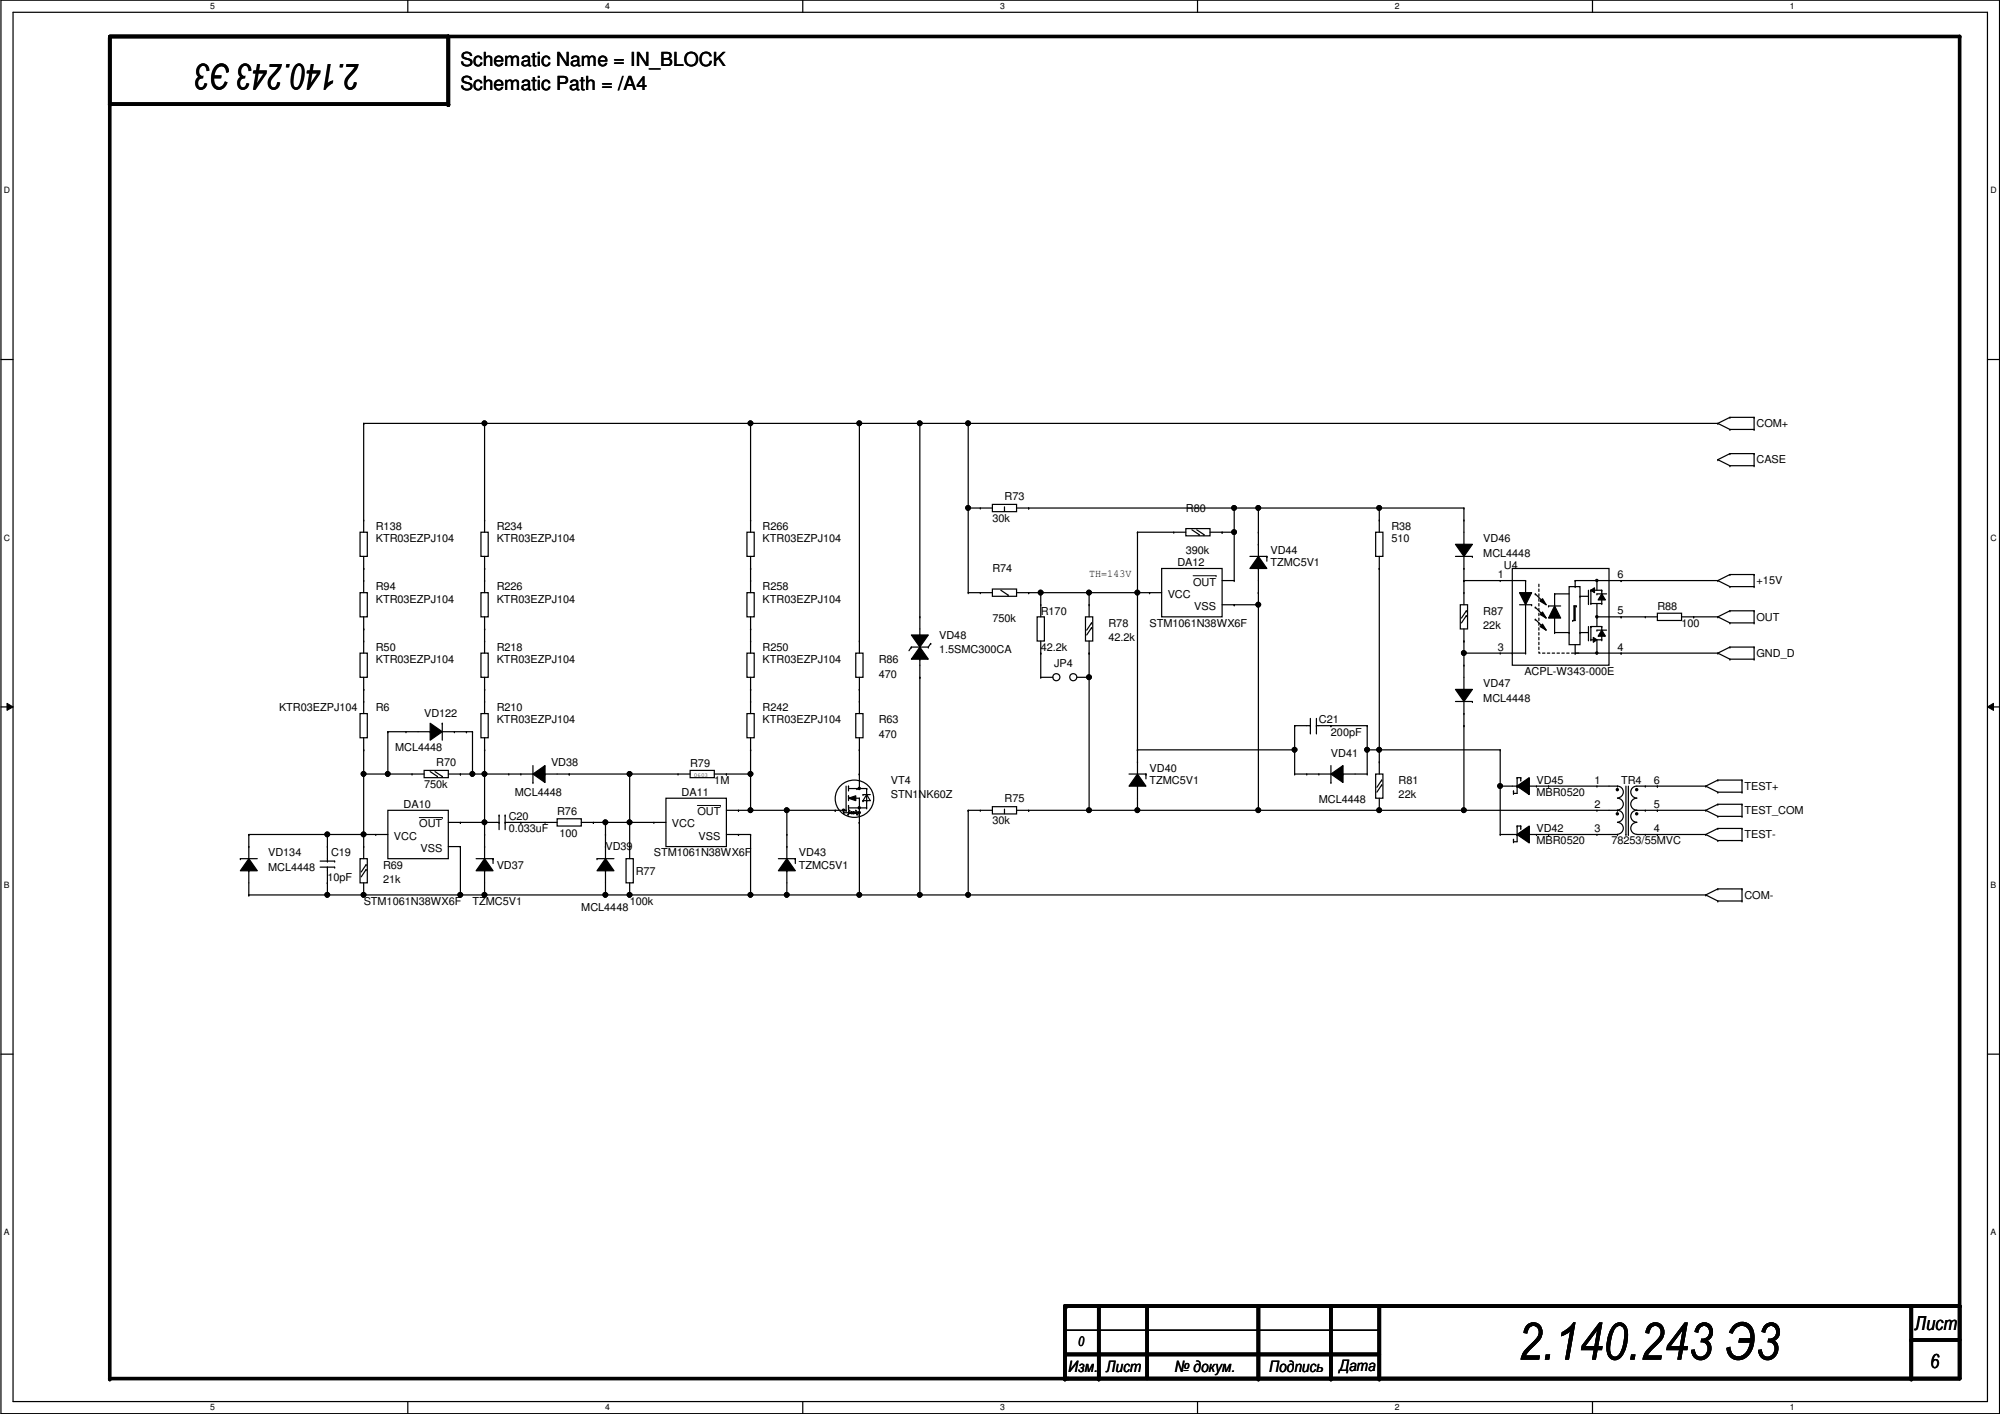
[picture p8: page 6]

Лист 2.140.243 Э3 Лист 2.140.243 Э3 Лист 2.140.243 Э3 6 ⁰ Изм. 6 ⁰ Изм. 6 ⁰

Лист | № докум. | Подпись | Дата

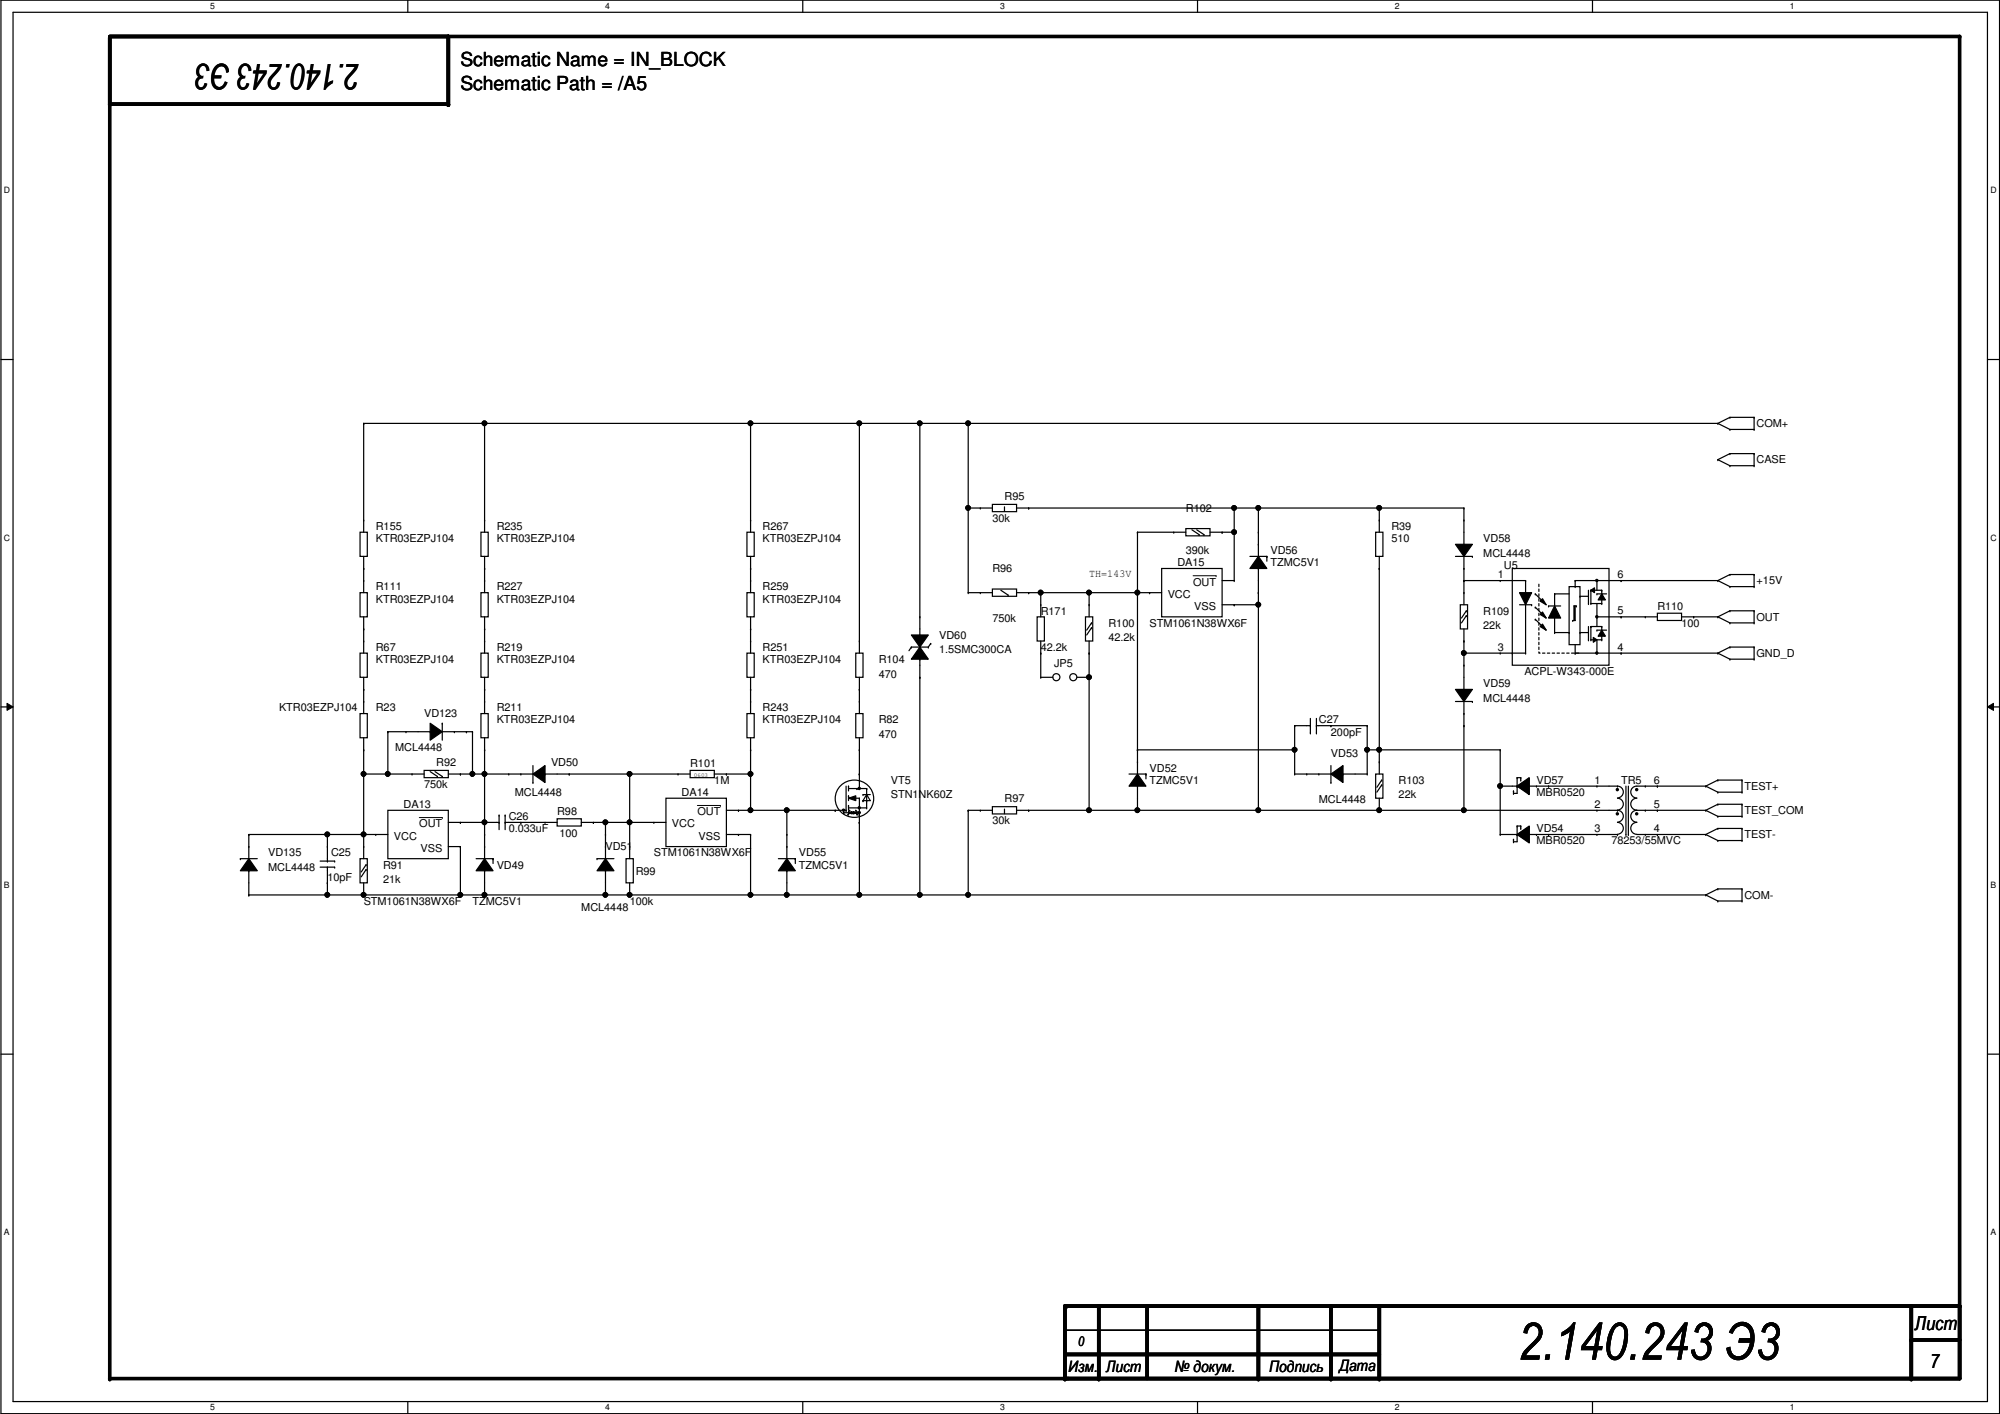
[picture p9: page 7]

Лист 2.140.243 Э3 Лист 2.140.243 Э3 Лист 2.140.243 Э3 7 ⁰ Изм. 7 ⁰ Изм. 7 ⁰

Лист | № докум. | Подпись | Дата

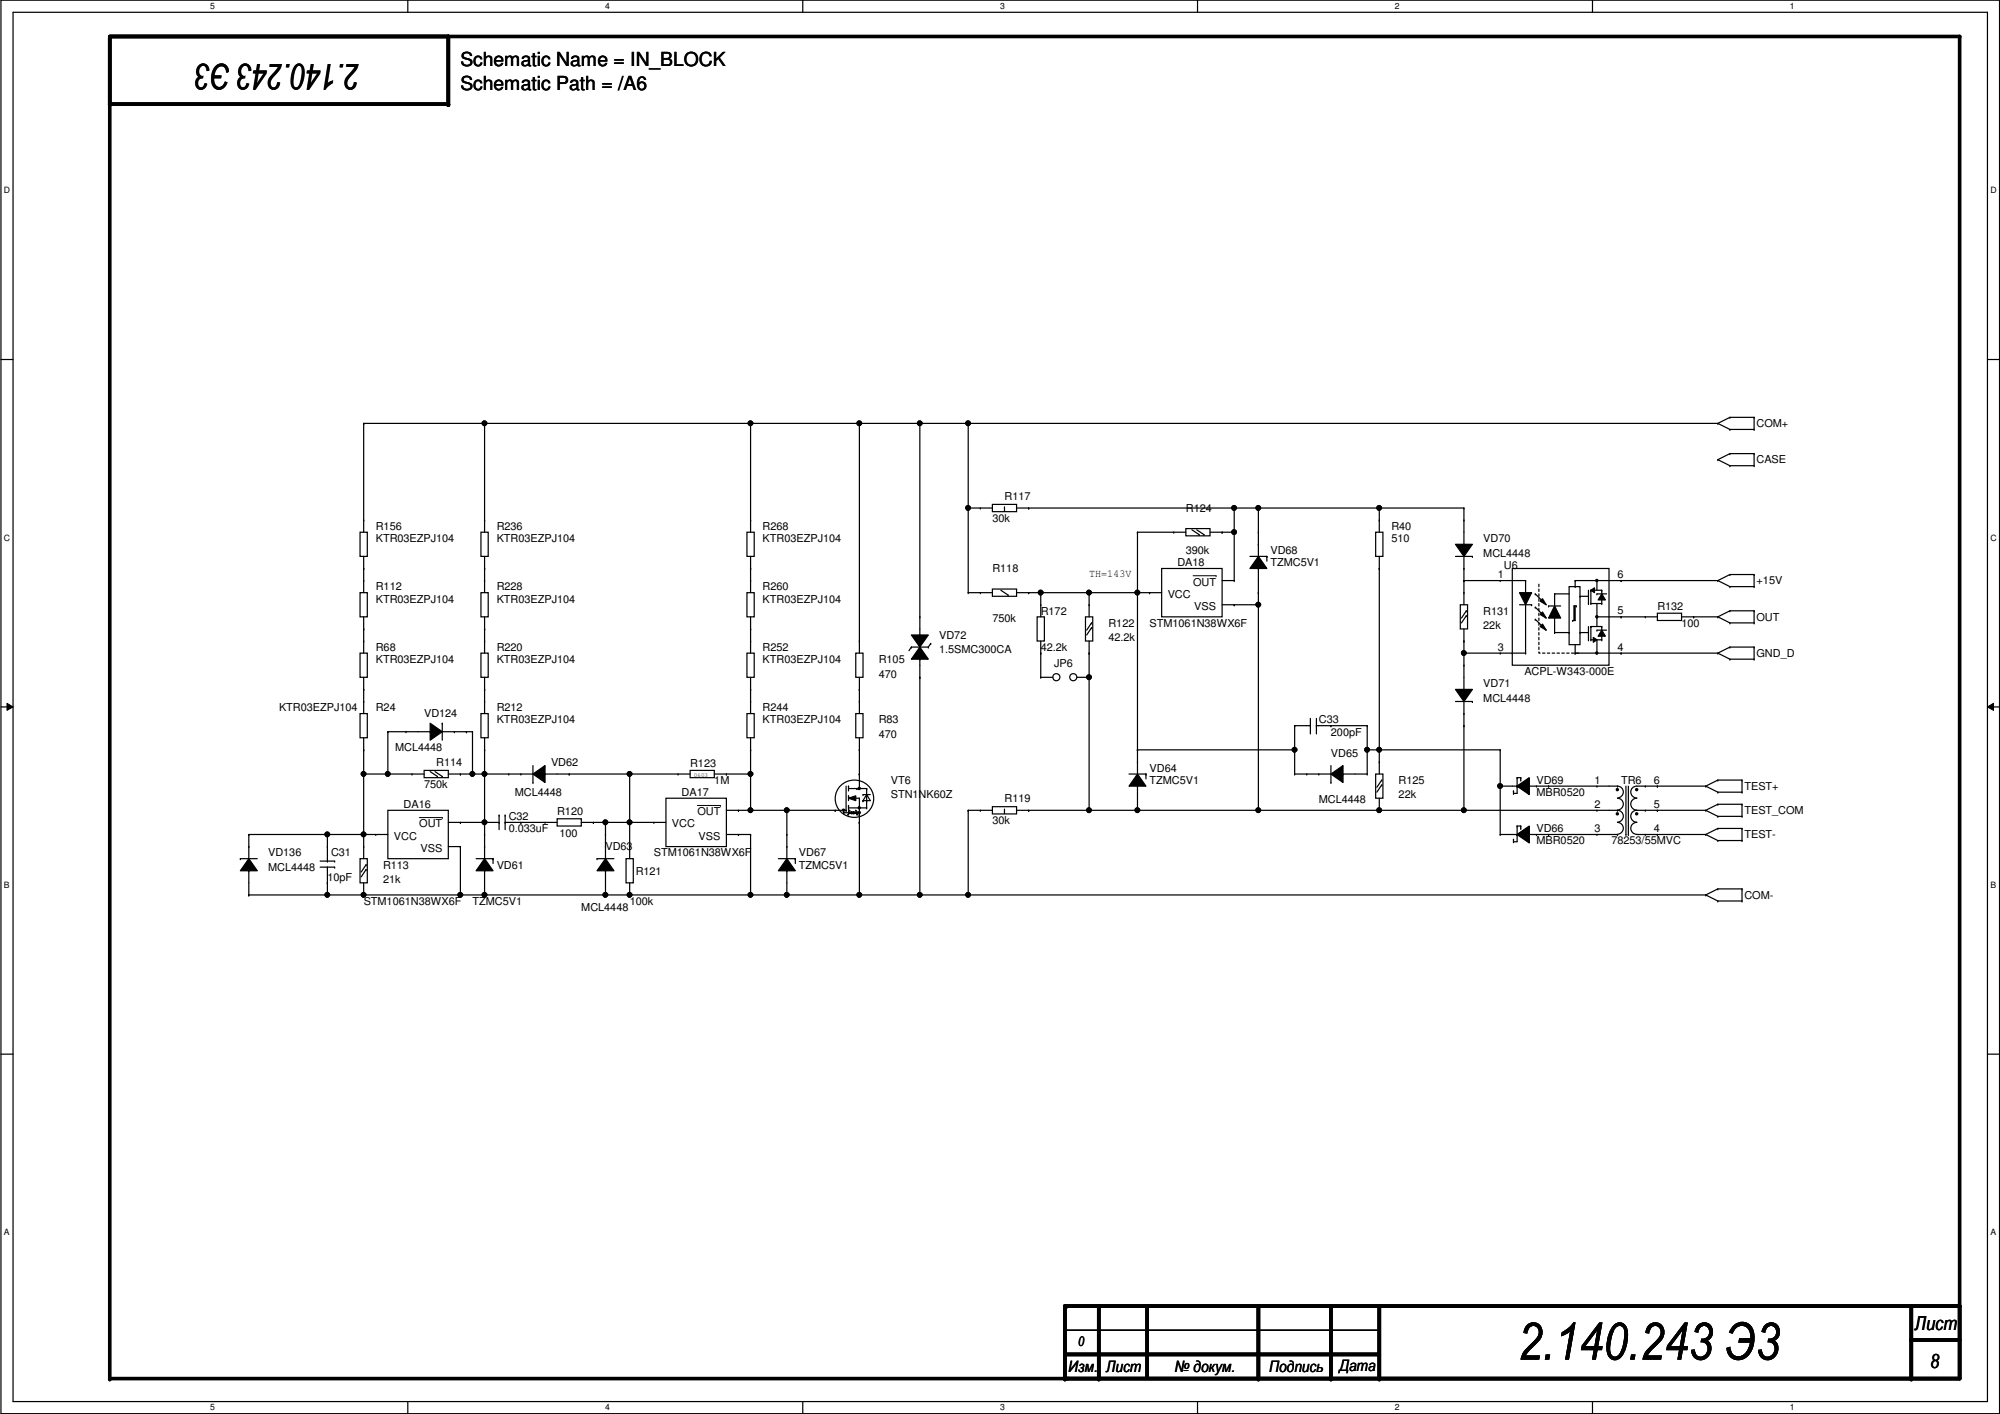
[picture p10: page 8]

Лист 2.140.243 Э3 Лист 2.140.243 Э3 Лист 2.140.243 Э3 8 ⁰ Изм. 8 ⁰ Изм. 8 ⁰

Лист | № докум. | Подпись | Дата

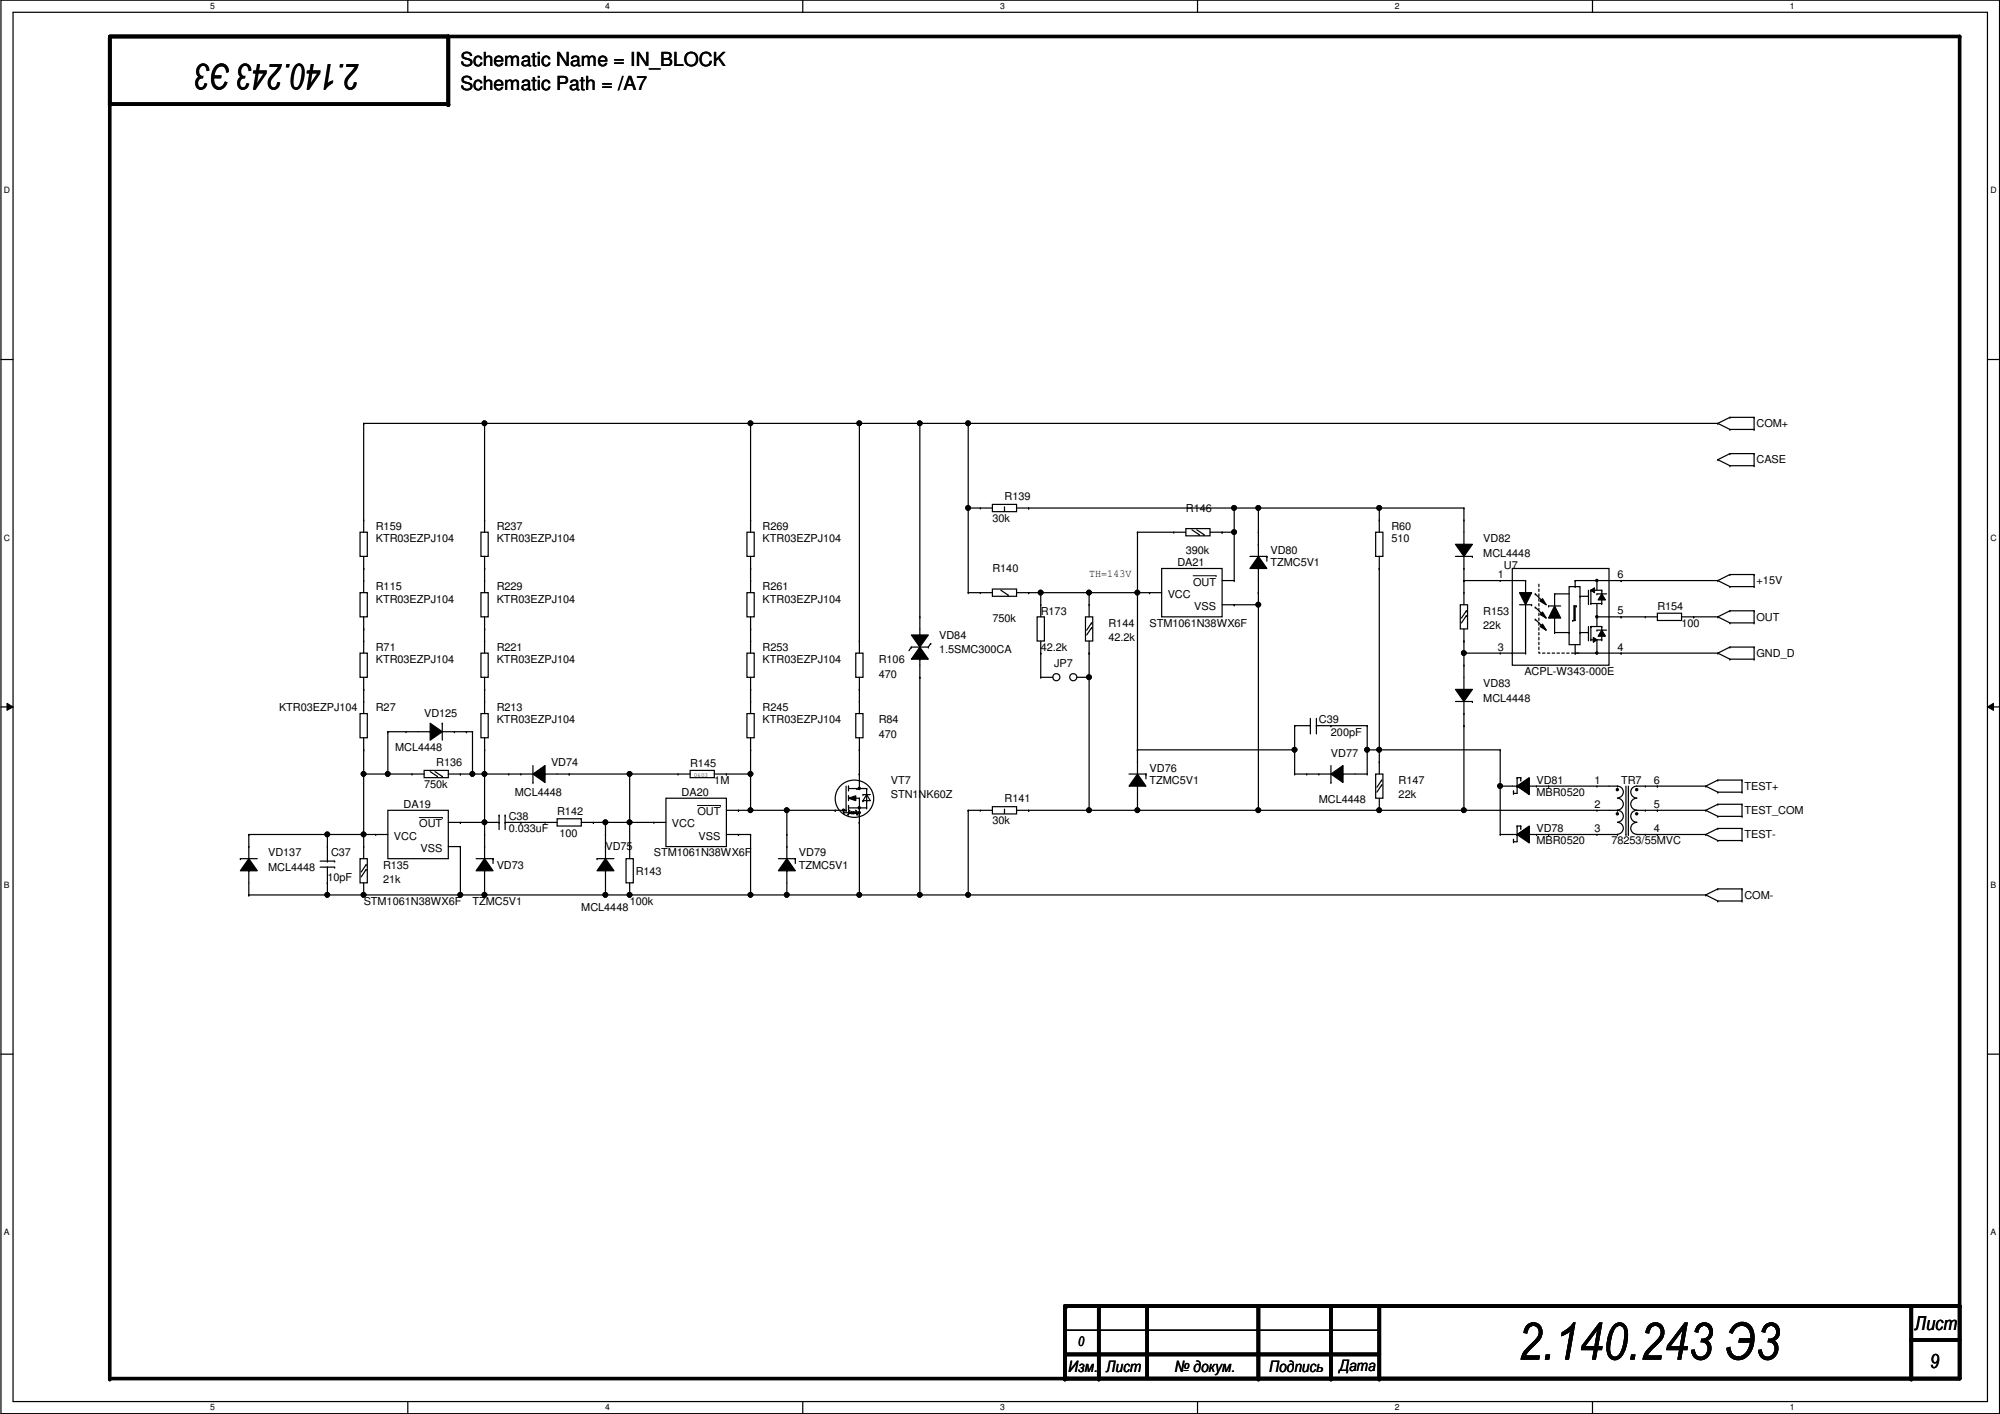
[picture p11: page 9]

Лист 2.140.243 Э3 Лист 2.140.243 Э3 Лист 2.140.243 Э3 9 ⁰ Изм. 9 ⁰ Изм. 9 ⁰

Лист | № докум. | Подпись | Дата

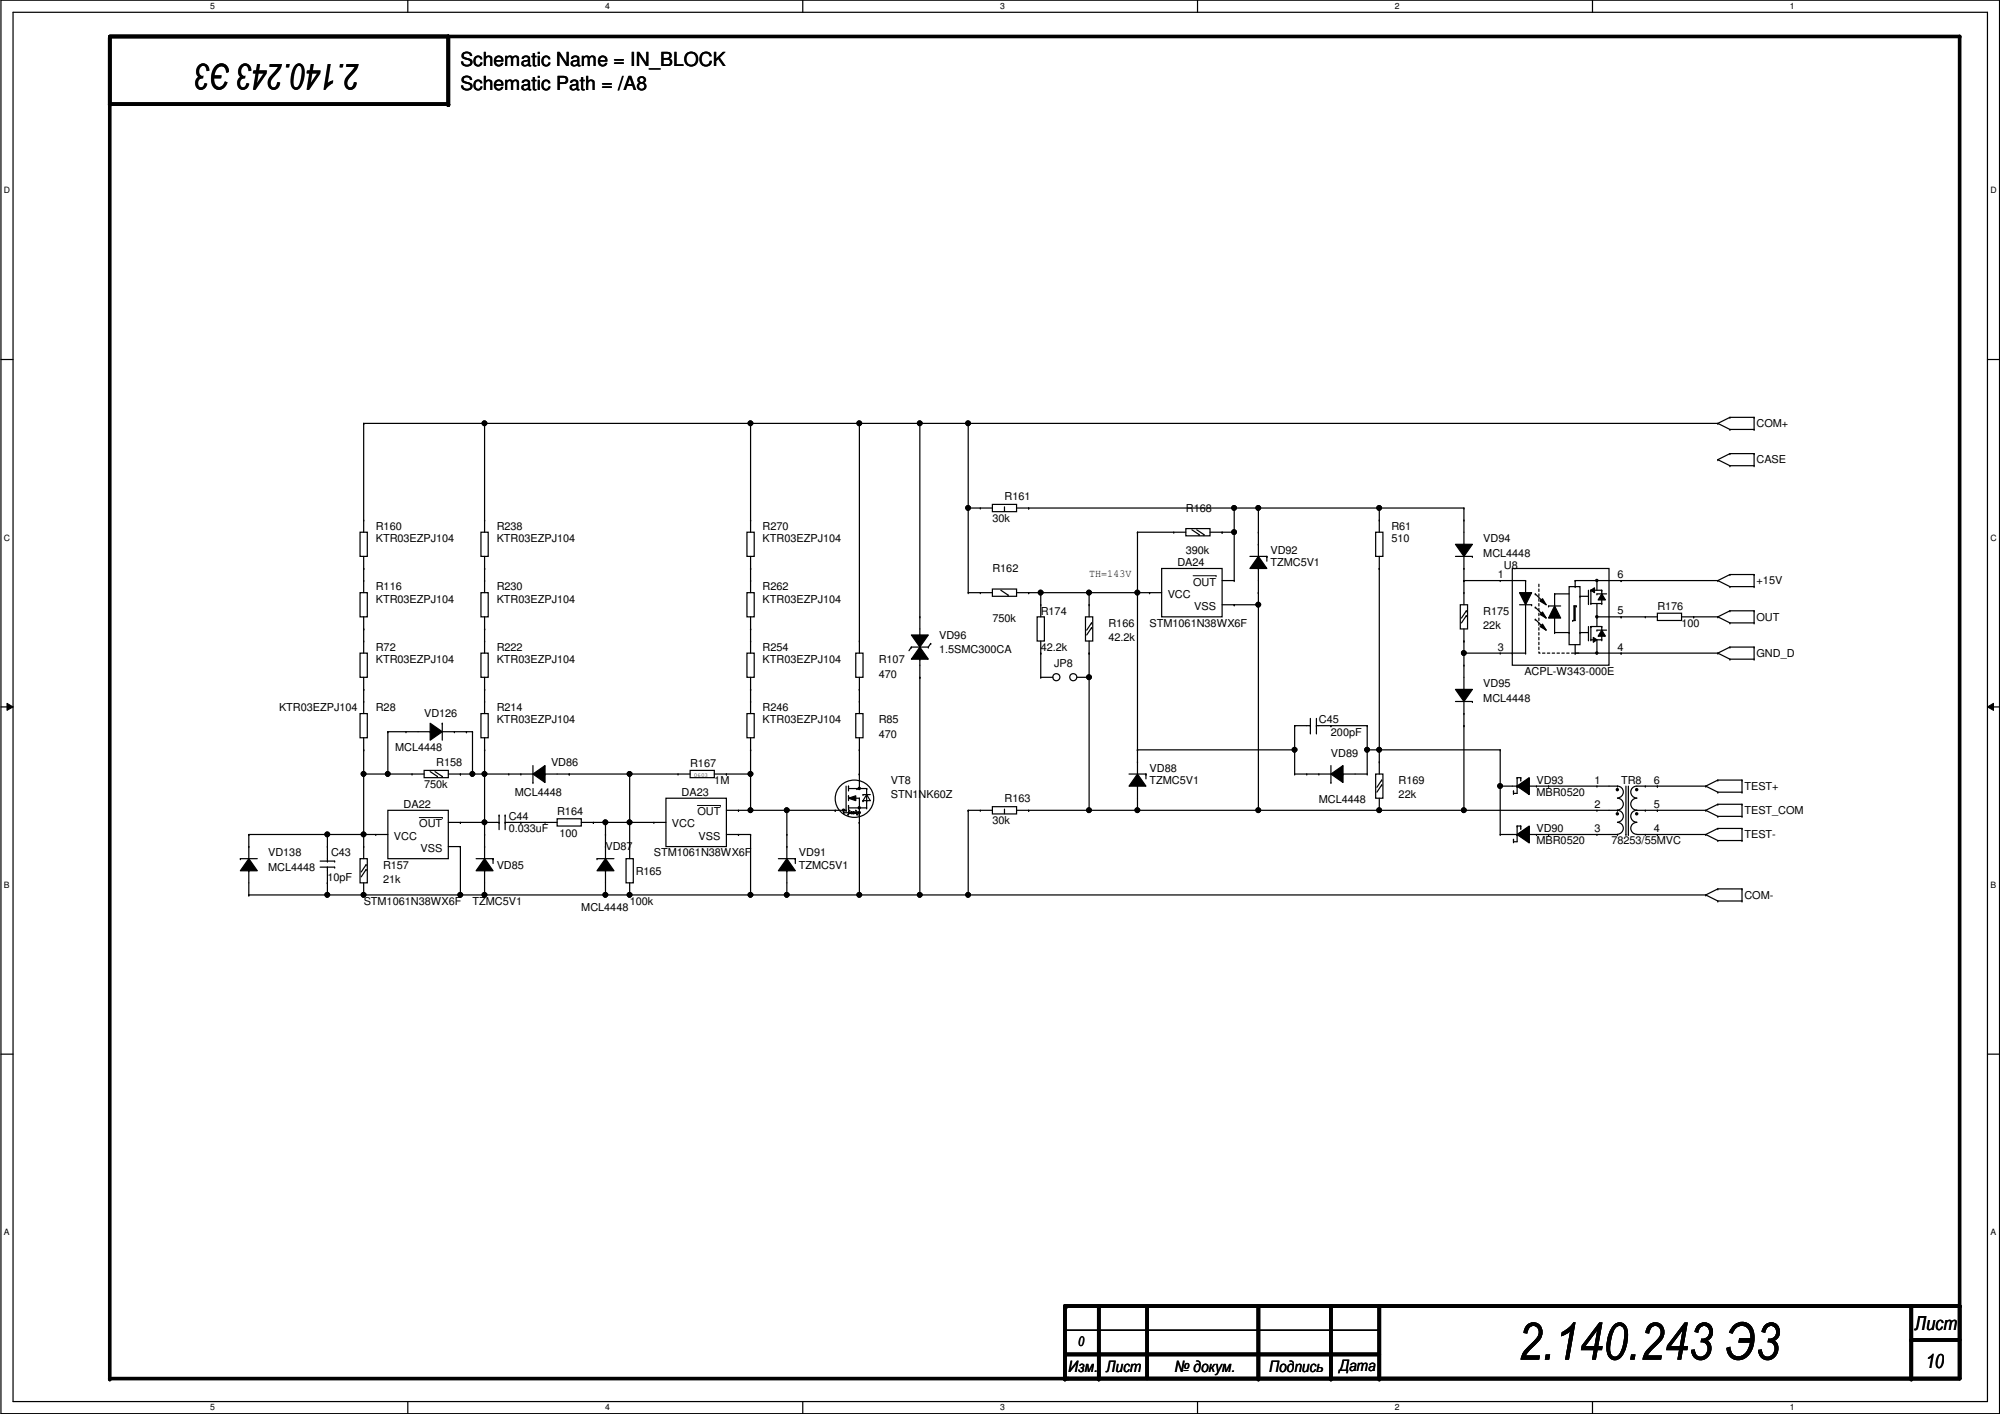
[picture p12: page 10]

Лист 2.140.243 Э3 Лист 2.140.243 Э3 Лист 2.140.243 Э3 10 ⁰ Изм. 10 ⁰ Изм. 10 ⁰

Лист | № докум. | Подпись | Дата

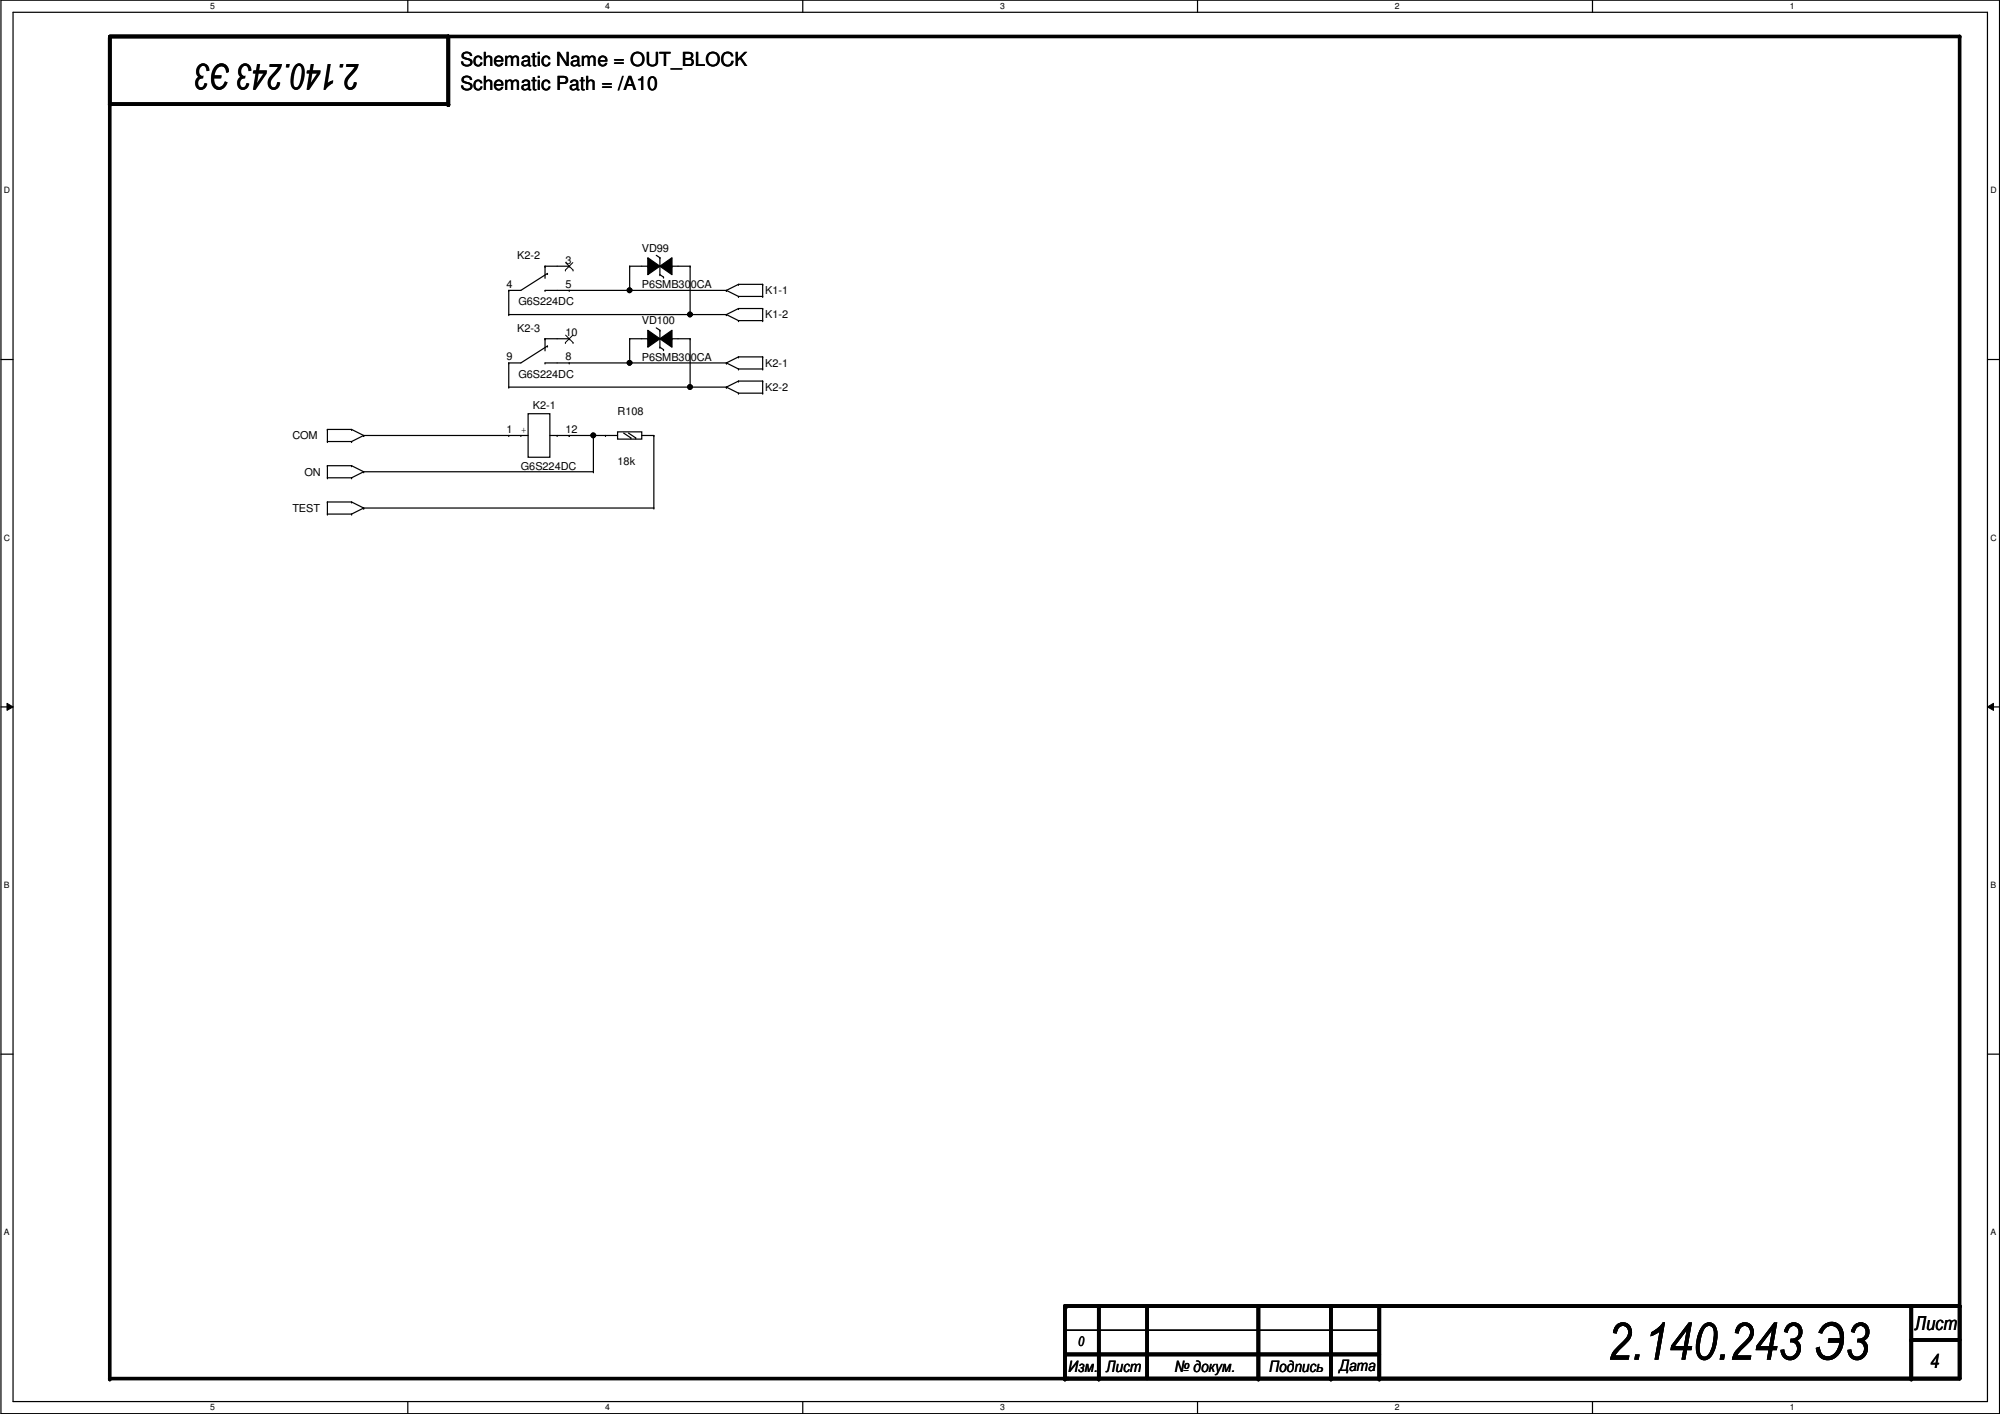
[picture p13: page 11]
COM; TEST; P6SMB300CA

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

Лист | № докум. | Подпись | Дата

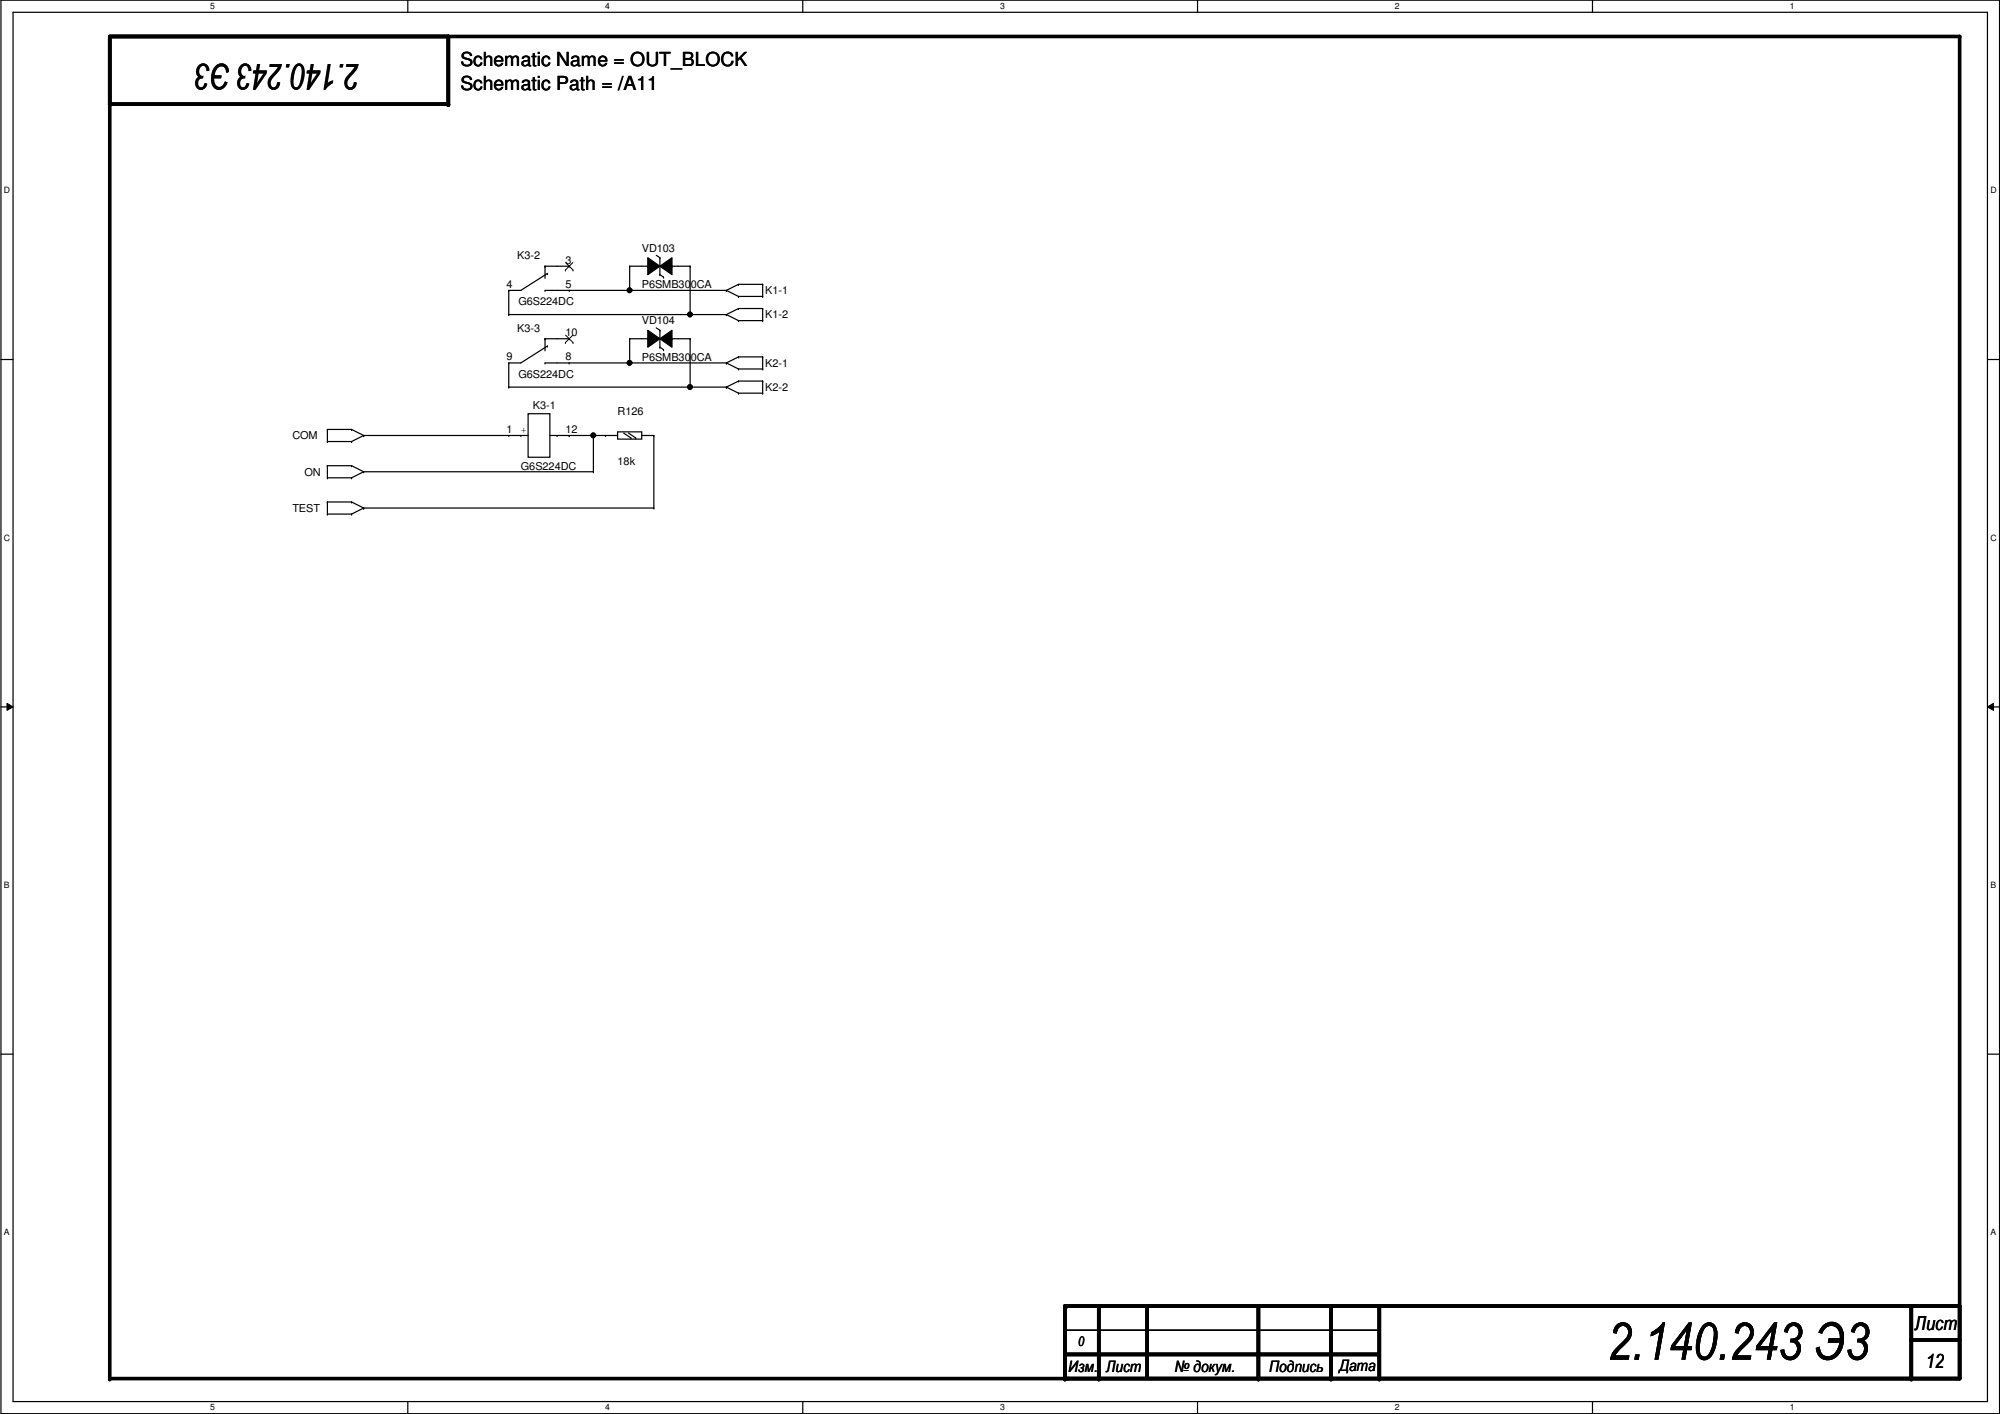
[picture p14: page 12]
COM; TEST; P6SMB300CA

Лист 2.140.243 Э3 Лист 2.140.243 Э3 Лист 2.140.243 Э3 12 ⁰ Изм. 12 ⁰ Изм. 12 ⁰

Лист | № докум. | Подпись | Дата

COM; TEST; P6SMB300CA

Лист 2.140.243 Э3 Лист 2.140.243 Э3 Лист 2.140.243 Э3 13 ⁰ Изм. 13 ⁰ Изм. 13 ⁰

Лист | № докум. | Подпись | Дата

COM; TEST; P6SMB300CA

Лист 2.140.243 Э3 Лист 2.140.243 Э3 Лист 2.140.243 Э3 14 ⁰ Изм. 14 ⁰ Изм. 14 ⁰

Лист | № докум. | Подпись | Дата

COM; TEST; P6SMB300CA

Лист 2.140.243 Э3 Лист 2.140.243 Э3 Лист 2.140.243 Э3 15 ⁰ Изм. 15 ⁰ Изм. 15 ⁰

Лист | № докум. | Подпись | Дата

COM; TEST; P6SMB300CA

Лист 2.140.243 Э3 Лист 2.140.243 Э3 Лист 2.140.243 Э3 16 ⁰ Изм. 16 ⁰ Изм. 16 ⁰

Лист | № докум. | Подпись | Дата

COM; TEST; P6SMB300CA

Лист 2.140.243 Э3 Лист 2.140.243 Э3 Лист 2.140.243 Э3 17 ⁰ Изм. 17 ⁰ Изм. 17 ⁰

Лист | № докум. | Подпись | Дата

COM; TEST; P6SMB300CA

Лист 2.140.243 Э3 Лист 2.140.243 Э3 Лист 2.140.243 Э3 18 ⁰ Изм. 18 ⁰ Изм. 18 ⁰

Лист | № докум. | Подпись | Дата

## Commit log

2015-11-24 Создано хранилище для плат KSK_02vX.
2015-12-22 первая версия от Феди смотрим, проверяем, учимся
    todo: убрать ненужные метки DRC
    [KSK.DSN, KSK.dsn, add_to_lib.xls]
2015-12-22 убрали ненужные DRC 1. same net spacing сделали -1 (!) и заработало, с нулем нет 2. линия то отверстие, обновили модули передатчика и приемника todo: понять какого не соединяются модули - есть RATS
2015-12-23 Изменена структура файлов. На схеме добавлены титулы и сделаны мелкие правки по оформлению. На плате mdd блок для выходов изменен на out_block1. В ограничениях изменены VIA. На плате исправлены все, 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
    [KSK.DSN, KSK.dsn, KSK_02v5.DSN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]
2015-12-23 Обновил статус разводки платы.
2015-12-23 Убрано большинство DRC. Остальные заигнорены. Переделаны модули IN_BLOCK и OUT_BLOCK Разводка (Основная часть) в сетке 0,635 Точка привязки - лапы трансформаторов или оптронов в модуле IN_BLOCK Добав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
    [KSK_02v5.DSN]
2015-12-23 10. Проверять разводк тестами Tools->Quick Reports: Устранены косяки по тестам Dangling Line, Via and Antenna Report Net Loop Reprot Net Single Pin and No Pin Shape Dynamic Status Shape Islands uncon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
    [KSK_02v5.DSN]
2015-12-24 1. схема без изменений 2. на плате подправлены 2.1. полигоны - убрана где не надо заливка без термобарьеров 2.2. цепи питания - в некоторых местах утолщены дорожки и добавлены дополнительные ПО
2015-12-24 Мелкие исправления платы.(подергал полигоны, вытащил дорожки из под лап микросхем) Переделал модули in_block добавил диодики VD131... в модулях для защиты от переполюсовки.
    [KSK_02v5.DSN]
2015-12-24 расстановка шелкографии началась
2015-12-24 Растаскал шелкографию ЗаАвтоСилкСкринил Вопрос??? Автосилк пожрал плюсики от диодов.
2015-12-25 Увеличены отступы шелкографии до КП у элементов в "pcb/symbols", для устранения лишних ошибок. Раздвинуты эелементы DD100 и DD101. Расставлена шелкография для первого дискретного входа, для остальных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
    [diomelf3521x140n.psm, pll_1_27.psm, resc1608x45n.psm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]
2015-12-28 Подправлена шелкография. Передвинута дорожка OUT1.
    [diom5436x230n.psm, diomelf1911n.psm, resc2013x50n.psm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]
2015-12-28 Сделано скругление углов.
2015-12-29 Подготовлены файлы для производства.
2015-12-29 Редактировал схему (для повышения понятности). Подкорректированы номиналы некоторых элементов. (В таком виде можно заказывать комплектацию) Заменены часть самодельных элементов, элементами из БД. Пла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
    [KSK_02v5.DSN]
2015-12-29 При вводе СП в 1С учесть что часть элементов отсутствует в БД. На сборочнике надо перевернуть один стабилитрон, спросить у Феди.
2016-02-04 На схеме все элементы привязаны к БД, у части элементов изменились посадочные места.
    [KSK_02v5.DSN]
2016-02-04 Добавлена спецификация.
    [KSK_02v5.DSN]
2016-02-05 Начато оформление сборочного чертежа.
2016-02-05 На нескольких посадочных местах изменен слой сборки. Сделан СБ.
    [diom7959x262n.psm, diomelf1911n.psm, diomelf3521x140n.psm]
2016-02-08 Добавлены замены для транзисторов.
2016-02-19 Исправлена дата в СП.
2016-04-13 В СП в поз.55 исправлено поз.обозначение U36 на DA25. То же самое сделано на схеме.
    [KSK_02v5.DSN]
2016-04-14 Добавлен pdf для схемы. На СБ КП сделаны более темными.
